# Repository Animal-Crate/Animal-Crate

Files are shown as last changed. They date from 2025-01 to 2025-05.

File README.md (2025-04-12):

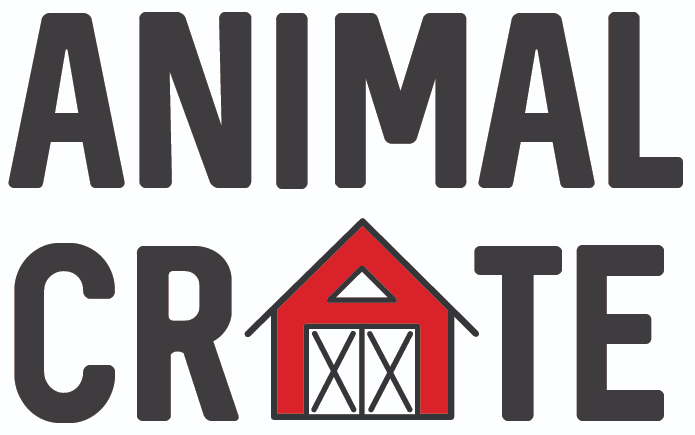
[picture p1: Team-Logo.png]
Animal Crate


This project is designed to create an animal noise toy that helps children to learn their animals and their sounds. It is specifically a toy that is meant to better cater to children and individuals with disabilities so that they can learn in a fun and constructive manner with a toy that is appealing and able to meet their needs.

This is a capstone project for the University of Kentucky ECE 490/491 that we are working on as a team. This is the public, open-source repository for this project and all code within this project falls under the provided license in this repository, AGPL-3.0 License. The provided schematics, CAD designs, and other resources are suggestions for recreating this project from home.

---

## Our Goal
The goal of this project is to design a child's toy that makes animal noises that is accessible to a wide-range of audiences, from children with disabilities or impairments to elderly with arthritis and compromised movement.

The provided code will be organized, commented, and user-friendly to allow for the ultimate configuration based on needs and systems. This is our goal as the members working on this project, to ensure that it is robust and well-rounded, allowing those without prior coding knowledge to make changes to suit their needs.

## Prerequisites
Before compiling the programming in this repository, some libraries are necessary for the Arduino IDE. These libraries are not all contained here due to licensing.

The following libraries are required for compiling and uploading to an ESP-32.
- The Animal Toy System utilizes the following libraries:
  - [Arduino LSM6DS3 Library](https://github.com/arduino-libraries/Arduino_LSM6DS3)
  - [DFPlayerMiniFast](https://github.com/PowerBroker2/DFPlayerMini_Fast)
- The Scanner System utilizes the following libraries:
  - [Adafruit ST7735 Library](https://github.com/adafruit/Adafruit-ST7735-Library) (For Testing)
  - [MFRC522](https://github.com/Animal-Crate/Animal-Crate/tree/master/MFRC522)
- The Sound System utilizes the following libraries:
  - [DFRobotDFPlayerMini](https://github.com/DFRobot/DFRobotDFPlayerMini)
  - [ESPSoftwareSerial](https://github.com/plerup/espsoftwareserial/)
- The Video/Algorithm System utilizes the following libraries:
  - [Adafruit GFX Library](https://github.com/adafruit/Adafruit-GFX-Library)
  - [Adafruit ILI9341 Library](https://github.com/adafruit/Adafruit_ILI9341)
  - [Adafruit ImageReader Library](https://github.com/adafruit/Adafruit_ImageReader)
  - [Adafruit SPIFlash](https://github.com/adafruit/Adafruit_SPIFlash)
  - [SdFat](https://github.com/greiman/SdFat)

## Acknowledgements
Please note that the files shown in [MFRC522](https://github.com/Animal-Crate/Animal-Crate/tree/master/_MFRC522) are taken from another repository. These are not licensed under this repository's license, and you can find more information in the README section in that directory.

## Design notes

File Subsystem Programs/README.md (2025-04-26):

The programs in this directory are intended for testing the individual systems within this project. This is a modular based project such that each subsystem can be tested individually to ensure they are working correctly and as intended. The programs are listed below for each part and how they work.

---
**NOTE**

These programs have **Prerequisites** for the libraries prior to compiling. It is suggested that you review these libraries on the front page to ensure that you have all of the necessary files for compiling in Arduino IDE. The links to the GitHub repositories for these are provided, but must be downloaded individually in the Arduino IDE if using it as the source for compilation to an ESP32 or other microcontroller.

---

### Algorithm-Feedback
The `Algorithm-Feedback.ino` file is used for testing the individual buttons (for the display), the display, and the learning/game modes within the program. This does not test the scanning and audio functions, but does test the display and buttons for manipulating the brightness, navigation, and functionality around the different modes in this project.

### Animal_Toy
The `Animal_Toy.ino` file is used for testing the individual toys and their functionalities, including the DFPlayer Minis that are used in each of the toys. This tests the gyro controls in the microcontrollers that were used in the toys, and is not necessary in the final project if ignoring the individual toys' functionality.

### Charge_Detection
The `Charge_Detection.ino` file is used for testing the functionality of the power LED in the system to display a color based on the charge of the system.

### Power-System_Debug
The `Power-System_Debug.ino` file is used for testing the functionality of a dedicated power system following the same design used in this project, which is 4 C-Type Batteries with components to step the voltage down for the required voltage for each of the parts used in this project in the other subsystems.

### Scanner_Debug & Scanner_Debug-Display
The `Scanner_Debug.ino` and `Scanner_Debug-Display.ino` files are used for testing the scanner functionality to serial connection and to display. These are intended to test the scanner and its primary functions within the project. The `Scanner_Debug.ino` tests the functionality of the Scanner itself without a display. The `Scanner_Debug-Display.ino` is intended to demonstrate the functionality of the Scanner in converting the UID of the NFC chip to a string value that can be used in the project.
- It is suggested to run both, if possible, to ensure that the NFC chips used have UIDs that can be properly displayed. The purpose of this is to ensure that the UID is within 32 characters, the maximum for the program, and that the display can show these appropriately so that it can be used within the program for comparing the animals later.

### Sound-System_Debug
The `Sound-System_Debug.ino`file is used for testing the audio subsystem by itself to ensure that the animals are played. This also tests the buttons associated with the sound system to ensure that they trigger the volume up/down and plays the audio. This is also used to ensure the correct wiring for the DFPlayer Mini. This is necessary for testing the functionality of the DFPlayer Mini due to the current draw.
- It is suggested to test the audio system by itself, since greater current draw, such as testing the scanner and display alongside the audio system, may cause issues with the DFPlayer Mini powering the speaker, depending on the speaker draw.

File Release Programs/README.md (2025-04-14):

This is the directory for releases. We will be posting updated programs for the releases here, and this will track the version history.

The `Control_Program-Serial_Debug.ino` file is a program for displaying to the Serial Window in the Arduino IDE.

The `Control_Program.ino` file is a program that does not display to Serial Window, but has the same functionality.

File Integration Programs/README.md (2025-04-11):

The provided files in this directory are for integration tests, and can be used to test multiple systems when recreating this project. Below are descriptions of the other files. Please refer to the [Prerequisites](https://github.com/Animal-Crate/Animal-Crate/blob/master/README.md) when downloading libraries for testing these integration programs.

### AV_ScannerIntegration
The `AV_ScannerIntegration.ino` file should be run in Arduino IDE for the appropriate setup. This may not perform correctly if executed in Platform IO due to the differences in the setup function for the display. This integration test is performed to ensure that the audio system, display/algorithm system, and scanner system work together.
- It is suggested to have the DFPlayer Mini running on a DC Power Supply at about 4.50 Volts and 0.021 A (21 mA) with a common ground for the ESP32 and DC Power Supply. The DFPlayer Mini, ILI9341 board, and scanner have a large combined amperage that the ESP32 may not be able to supply, causing the audio system to not work as intended.

### ScannerAudioIntegration
The `ScannerAudioIntegration.ino` file should be run in Arduino IDE, but may work in the Platform IO if necessary to test there. This integration test is performed to ensure the audio system works as intended alongside the scanner system, and is also a separate test for ensuring that the scanning system works as intended with NFC Chips that are written into the program. This does not contain the updated functions used in the `AV_ScannerIntegration.ino` file, but contains the same structure, so testing should work seamlessly across both systems when testing scanner and audio.

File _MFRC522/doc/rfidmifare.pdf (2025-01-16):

## Using a MFRC522 reader to read and write MIFARE RFID cards

on ARDUINO through the MFRC522 library BY COOQROBOT.
Mario Capurso (m.capurso@libero.it)

MIFARE is the NXP Semiconductors-owned trademark of a series of chips widely
used in contactless smart cards and proximity cards. According to the producers, billions of smart card chips and many millions of reader modules have been sold. [1]

The technology is owned by NXP Semiconductors (spin off from Philips Electronics in 2006) with headquarters in Eindhoven, Netherlands, and main business sites in Nijmegen, Netherlands, and Hamburg, Germany.

The MIFARE name covers proprietary technologies based upon various levels of the ISO/IEC 14443 Type A 13.56 MHz contactless smart card standard.
The MIFARE name (derived from the term MIkron FARE Collection System) covers
seven different kinds of contactless cards.

MIFARE Classic employs a proprietary protocol compliant to parts (but not all) of ISO/IEC 14443-3 Type A, with an NXP proprietary security protocol for authentication and ciphering.

The MIFARE Classic card is fundamentally just a memory storage device, where the memory is divided into segments and blocks with simple security mechanisms for access control. They are ASIC-based and have limited computational power. Thanks
to their reliability and low cost, those cards are widely used for electronic wallet, access control, corporate ID cards, transportation or stadium ticketing.

The MIFARE Classic 1K offers 1024 bytes of data storage, split into 16 sectors; each sector is protected by two different keys, called A and B. Each key can be programmed to allow operations such as reading, writing, increasing valueblocks, etc. MIFARE Classic 4K offers 4096 bytes split into forty sectors, of which 32 are same size as in the 1K with eight more that are quadruple size sectors. MIFARE Classic mini offers 320 bytes split into five sectors.

For each of these card types, 16 bytes per sector are reserved for the keys and access conditions and can not normally be used for user data. Also, the very first 16 bytes contain the serial number of the card and certain other manufacturer data and are read only. That brings the net storage capacity of these cards down to 752 bytes for MIFARE Classic 1k, 3440 bytes for MIFARE Classic 4k, and 224 bytes for Mini. It uses an NXP proprietary security protocol (Crypto-1) for authentication and ciphering.

The encryption used by the MIFARE Classic card uses a 48 bit key. [18]
A presentation by Henryk Plötz and Karsten Nohl[19] at the Chaos Communication Congress in December 2007 described a partial reverse-engineering of the algorithm used in the MIFARE Classic chip. Abstract and slides[20] are available online. A paper that describes the process of reverse engineering this chip was published at the August 2008 USENIX security conference.[21] (https://www.usenix.org/legacy/events/sec08/tech/full_papers/nohl/nohl.pdf)

In March 2008 the Digital Security[22] research group of the Radboud University Nijmegen made public that they performed a complete reverse-engineering and
were able to clone and manipulate the contents of an OV-Chipkaart which is a MIFARE Classic card.[23] (http://www.cs.ru.nl/~flaviog/publications/Talk.Mifare.pdf) For demonstration they used the Proxmark device, a 125 kHz / 13.56 MHz research instrument.[24] The schematics and software are released under the free GNU General Public License by Jonathan Westhues in 2007. They demonstrate it is even possible to perform card-only attacks using just an ordinary stock-commercial NFC reader in combination with the libnfc library.

In April 2009 new and better card-only attack on MIFARE Classic has been
found. It was first announced at the Rump session of Eurocrypt 2009.[35] This attack was presented at SECRYPT 2009.[36] The full description of this latest and fastest attack to date can also be found in the IACR preprint archive.[37] The new attack improves by a factor of more than 10 all previous card-only attacks on MIFARE Classic, has instant running time, and it does not require a costly precomputation.

The new attack allows to recover the secret key of any sector of MIFARE Classic card via wireless interaction, within about 300 queries to the card. It can then be combined with the nested authentication attack in the Nijmegen Oakland paper to recover subsequent keys almost instantly. Both attacks combined and with the right hardware equipment such as Proxmark3, one should be able to clone any MIFARE Classic card in not more than 10 seconds. This is much faster than previously thought.

The MFRC522 is a highly integrated reader/writer IC for contactless communication at 13.56 MHz. The MFRC522 reader supports ISO/IEC 14443 A/MIFARE mode.
The MFRC522’s internal transmitter is able to drive a reader/writer antenna designed to communicate with ISO/IEC 14443 A/MIFARE cards and transponders without additional active circuitry. The receiver module provides a robust and efficient implementation for demodulating and decoding signals from ISO/IEC 14443 A/MIFARE compatible cards and transponders. The digital module manages the complete ISO/IEC 14443 A framing and error detection (parity and CRC) functionality.

The MFRC522 supports all variants of the MIFARE Mini, MIFARE 1K, MIFARE 4K, MIFARE Ultralight, MIFARE DESFire EV1 and MIFARE Plus RF identification protocols. To aid readability throughout this data sheet, the MIFARE Mini,

MIFARE 1K, MIFARE 4K, MIFARE Ultralight, MIFARE DESFire EV1 and MIFARE Plus products and protocols have the generic name MIFARE.

The following host interfaces are provided:

- Serial Peripheral Interface (SPI)
- Serial UART (similar to RS232 with voltage levels dependant on pin voltage supply)
- I2C-bus interface


Answer to Request :

With the Answer to Request sequence the MIFARE® RWD (Read Write Device) requests all MIFARE® cards in the antenna field. When a card is in the operating range of a RWD, the RWD continues communication with the appropriate protocol.

Anticollision loop
In the Anticollision loop the serial number of the card is read. If there are several cards in the operating range of a RWD they can be distinguished by their different serial numbers and one can be selected (Select card) for further transactions. The unselected cards return to the standby mode and wait for a new Answer to Request and Anticollision loop.

Select Card
With the Select Card command the RWD selects one individual card for further authentication and memory related operations. The card returns the Answer to Select (ATS) code, which determines the individual type of the selected card.

Access Specification
After identification and selection of one card the RWD specifies the memory location of the following access.

Three Pass Authentication
The appropriate access key for the previously specified access is used for 3 Pass Authentication. Any communication after authentication is automatically encrypted at the sender and decrypted by the receiver.

Read/Write

After authentication any of the following operations may be performed:

READ | reads one block
WRITE | writes one block
DECREMENT | decrements the contents of one block and stores the result
| in the data-register
INCREMENT | increments the contents of one block and stores the result
| in the data-register
TRANSFER | writes the contents of the data-register to one block
RESTORE | stores the contents of one block in the data-register

The MF1ICS50 IC of a Mifare Classic has integrated a 8192 Bit EEPROM which is split into 16 sectors with 4 blocks. One block consists of 16 bytes (1 Byte = 8 Bit).


Manufacturer Code (Block 0 of Sector 0)

The first block of the memory is reserved for manufacturer data like 32 bit serial number. This is a read only block. In many documents it is named "Block 0".

Data Block (Block 0 to 3 except "Block 0")

Access conditions for the Data Blocks are defined in the Sector Trailers. According to these conditions data can be read, written, incremented, decremented, transferred or restored either with Key A, Key B or never.

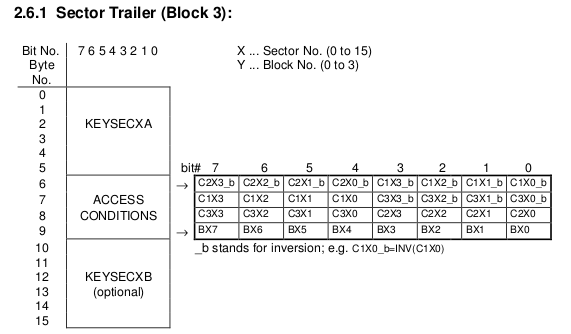
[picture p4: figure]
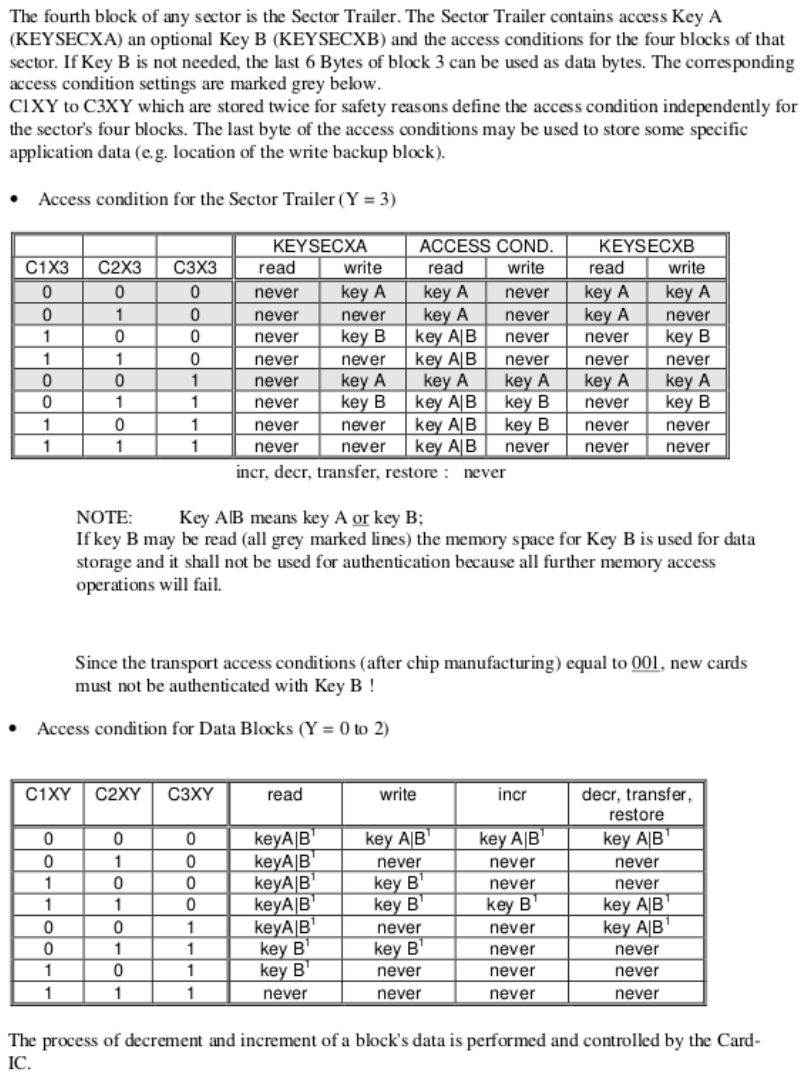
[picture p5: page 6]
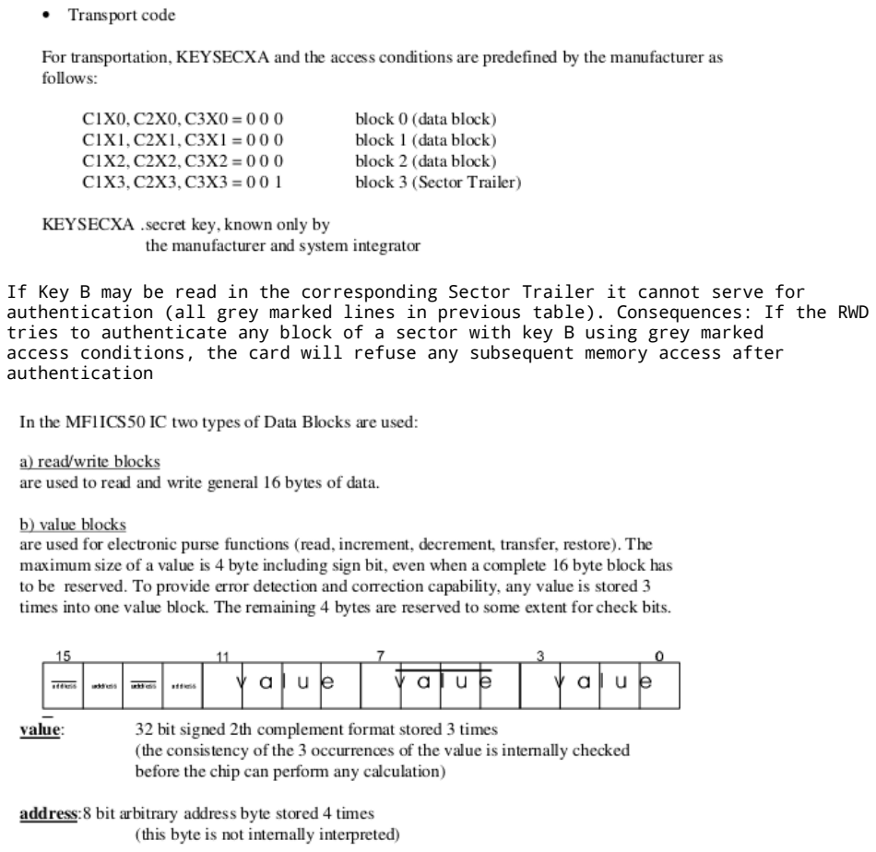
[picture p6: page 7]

If Key B may be read in the corresponding Sector Trailer it cannot serve for authentication (all grey marked lines in previous table). Consequences: If the RWD tries to authenticate any block of a sector with key B using grey marked
access conditions, the card will refuse any subsequent memory access after authentication

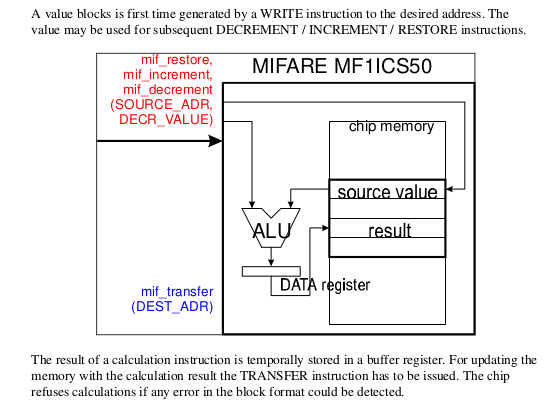
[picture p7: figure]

The described memory organization makes it possible to appoint different sectors to different applications and to prevent data corruption by using application specific secret keys. Keys can only be altered by a RWD which has stored the actual Key A or Key B if this is allowed according to access conditions. Otherwise the actual key cannot be changed anymore.

Before the execution of a command the correct format of the Access Conditions is checked by the Card-IC. Thus, when programming the Sector Trailer the card needs to be fixed within the operating range of a RWD's antenna to prevent interruption of the write operation because any unsuccessful write operation may lead to blocking the whole sector.

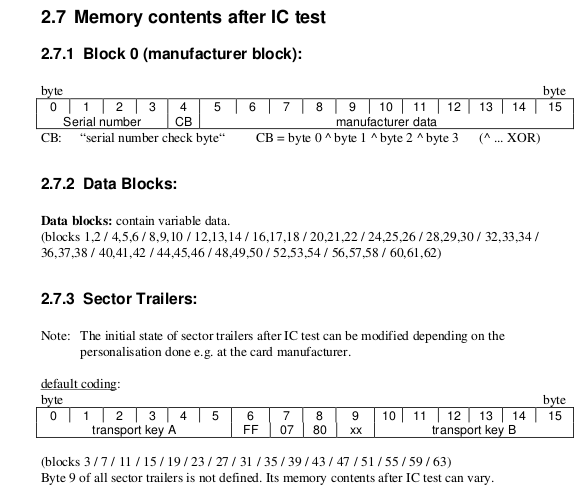
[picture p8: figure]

## MFRC522.h – A Library to use ARDUINO RFID MODULE KIT 13.56

MHZ BY COOQROBOT.

There are three hardware components involved:

1) The micro controller: An Arduino
2) The PCD (Proximity Coupling Device): NXP MFRC522 Contactless Reader IC
3) The PICC (short for Proximity Integrated Circuit Card): A card or tag using the ISO 14443A interface, eg Mifare or NTAG203.

MIFARE Classic 1K (MF1S503x):

Has 16 sectors * 4 blocks/sector * 16 bytes/block = 1024 bytes. The blocks are numbered 0-63.

Block 3 in each sector is the Sector Trailer.
* | Bytes 0-5: | Key A
* | Bytes 6-8: | Access Bits
* | Bytes 9: | User data
* | Bytes 10-15: Key B (or user data)

Block 0 is read only manufacturer data.

To access a block, an authentication using a key from the block's sector must be performed first.

Example: To read from block 10, first authenticate using a key from sector 3 (blocks 8-11).

All keys are set to FFFFFFFFFFFFh at chip delivery.

Warning: Please read section 8.7 "Memory Access". It includes this text: if the PICC detects a format violation the whole sector is irreversibly blocked.

To use a block in "value block" mode (for Increment/Decrement operations) you need to change the sector trailer. Use PICC_SetAccessBits() to calculate the bit patterns.

Commands sent to the PICC.

The commands used by the PCD to manage communication with several PICCs (ISO 14443-3, Type A, section 6.4)

PICC_CMD_REQA = 0x26,
REQuest command, Type A. Invites PICCs in state IDLE to go to READY and prepare for anticollision or selection. 7 bit frame.
PICC_CMD_WUPA = 0x52,
Wake-UP command, Type A. Invites PICCs in state IDLE and HALT to go to READY(*) and prepare for anticollision or selection. 7 bit frame.
PICC_CMD_CT = 0x88,
Cascade Tag. Not really a command, but used during anti collision. PICC_CMD_SEL_CL1 = 0x93,
Anti collision/Select, Cascade Level 1
PICC_CMD_SEL_CL2 = 0x95,
Anti collision/Select, Cascade Level 2 PICC_CMD_SEL_CL3 = 0x97,
Anti collision/Select, Cascade Level 3
PICC_CMD_HLTA = 0x50,
HaLT command, Type A. Instructs an ACTIVE PICC to go to state HALT.

The commands used for MIFARE Classic
Use PCD_MFAuthent to authenticate access to a sector, then use these commands to read/write/modify the blocks on the sector.
The read/write commands can also be used for MIFARE Ultralight.

PICC_CMD_MF_AUTH_KEY_A = 0x60,
Perform authentication with Key A
PICC_CMD_MF_AUTH_KEY_B = 0x61,
Perform authentication with Key B
PICC_CMD_MF_READ | = 0x30,
Reads one 16 byte block from the authenticated sector of the PICC. Also used for MIFARE Ultralight.
PICC_CMD_MF_WRITE | = 0xA0,
Writes one 16 byte block to the authenticated sector of the PICC. Called "COMPATIBILITY WRITE" for MIFARE Ultralight.
PICC_CMD_MF_DECREMENT = 0xC0,
Decrements the contents of a block and stores the result in the internal data register.
PICC_CMD_MF_INCREMENT = 0xC1,
Increments the contents of a block and stores the result in the internal data register.
PICC_CMD_MF_RESTORE | = 0xC2,
Reads the contents of a block into the internal data register. PICC_CMD_MF_TRANSFER = 0xB0,
Writes the contents of the internal data register to a block.

List of the functions in the library

Functions for setting up the Arduino

MFRC522(byte chipSelectPin, byte resetPowerDownPin);
void setSPIConfig();

Basic interface functions for communicating with the MFRC522

void PCD_WriteRegister(byte reg, byte value);
void PCD_WriteRegister(byte reg, byte count, byte *values);
byte PCD_ReadRegister(byte reg);
void PCD_ReadRegister(byte reg, byte count, byte *values, byte rxAlign = 0); void setBitMask(unsigned char reg, unsigned char mask);
void PCD_SetRegisterBitMask(byte reg, byte mask);
void PCD_ClearRegisterBitMask(byte reg, byte mask);
byte PCD_CalculateCRC(byte *data, byte length, byte *result);

Functions for manipulating the MFRC522

void PCD_Init();
void PCD_Reset();
void PCD_AntennaOn();

Functions for communicating with PICCs

byte PCD_TransceiveData(byte *sendData, byte sendLen, byte *backData, byte *backLen, byte *validBits = NULL, byte rxAlign = 0, bool checkCRC = false);

byte PCD_CommunicateWithPICC(byte command, byte waitIRq, byte *sendData, byte sendLen, byte *backData = NULL, byte *backLen = NULL, byte *validBits = NULL, byte rxAlign = 0, bool checkCRC = false);

byte PICC_RequestA(byte *bufferATQA, byte *bufferSize);
byte PICC_WakeupA(byte *bufferATQA, byte *bufferSize);
byte PICC_REQA_or_WUPA( byte command, byte *bufferATQA, byte *bufferSize); byte PICC_Select(Uid *uid, byte validBits = 0);
byte PICC_HaltA();

Functions for communicating with MIFARE PICCs

byte PCD_Authenticate(byte command, byte blockAddr, MIFARE_Key *key, Uid *uid); void PCD_StopCrypto1();
byte MIFARE_Read(byte blockAddr, byte *buffer, byte *bufferSize);
byte MIFARE_Write(byte blockAddr, byte *buffer, byte bufferSize);
byte MIFARE_Decrement(byte blockAddr, long delta);
byte MIFARE_Increment(byte blockAddr, long delta);
byte MIFARE_Restore(byte blockAddr);
byte MIFARE_Transfer(byte blockAddr);
byte MIFARE_Ultralight_Write(byte page, byte *buffer, byte bufferSize);

Support functions

byte PCD_MIFARE_Transceive( byte *sendData, byte sendLen, bool acceptTimeout = false);
const char *GetStatusCodeName(byte code);
byte PICC_GetType(byte sak);
const char *PICC_GetTypeName(byte type);
void PICC_DumpToSerial(Uid *uid);
void PICC_DumpMifareClassicToSerial(Uid *uid, byte piccType, MIFARE_Key *key);
void PICC_DumpMifareClassicSectorToSerial(Uid *uid, MIFARE_Key *key, byte sector); void PICC_DumpMifareUltralightToSerial();
void MIFARE_SetAccessBits(byte *accessBitBuffer, byte g0, byte g1, byte g2, byte g3);

Convenience functions - does not add extra functionality

bool PICC_IsNewCardPresent();
bool PICC_ReadCardSerial();

Detailed documentation – enum and structures

PICC types we can detect. Remember to update PICC_GetTypeName() if you add more.

enum PICC_Type

Return codes from the functions in this class. Remember to update GetStatusCodeName() if you add more.

enum StatusCode

A struct used for passing the UID of a PICC.

typedef struct {
byte | size; | Number of bytes in the UID. 4, 7 or 10.
byte | uidByte[10];
byte | sak; | The SAK (Select acknowledge) byte returned
| | from the PICC after successful selection.
} Uid

A struct used for passing a MIFARE Crypto1 key

typedef struct {
byte | keyByte[MF_KEY_SIZE];
} MIFARE_Key;

Example:
// Prepare key - all keys are set to FFFFFFFFFFFFh at chip delivery from the factory. MFRC522::MIFARE_Key key;
for (byte i = 0; i < 6; i++) key.keyByte[i] = 0xFF;

Member variables

Uid uid; | Used by PICC_ReadCardSerial().

Detailed documentation – functions

+Create object instance
MFRC522(
byte chipSelectPin, Arduino pin used for SPI chip select byte resetPowerDownPin Arduino pin used for SPI reset
);
Example:
#include <SPI.h>

#include <MFRC522.h>

#define SS_PIN 10 //Arduino Uno

#define RST_PIN 9

MFRC522 mfrc522(SS_PIN, RST_PIN); | // Create MFRC522 instance.

+Initializes the MFRC522 chip.
void MFRC522::PCD_Init()
Example:
void setup() {
Serial.begin(9600); | // Init serial communications with PC
SPI.begin(); | // Init SPI bus
mfrc522.PCD_Init(); | // Init MFRC522 card
}

+Set SPI bus to work with MFRC522 chip.

Please call this function if you have changed the SPI config since the MFRC522 constructor was run.

void MFRC522::setSPIConfig()

+Performs a soft reset on the MFRC522 chip and waits for it to be ready again. void MFRC522::PCD_Reset()

+Turns the antenna on by enabling pins TX1 and TX2.
After a reset these pins are disabled.
void MFRC522::PCD_AntennaOn()

+Transmits a REQuest command, Type A. Invites PICCs in state IDLE to go to READY and prepare for anticollision or selection. 7 bit frame.
Beware: When two PICCs are in the field at the same time I often get STATUS_TIMEOUT -probably due do bad antenna design.
return STATUS_OK on success, STATUS_??? otherwise.
byte MFRC522::PICC_RequestA(
byte *bufferATQA, The buffer to store the ATQA (Answer to request) in
byte *bufferSize Buffer size, at least two bytes. Also number of bytes returned if STATUS_OK.

+Transmits a Wake-UP command, Type A. Invites PICCs in state IDLE and HALT to go to READY(*) and prepare for anticollision or selection. 7 bit frame.
Beware: When two PICCs are in the field at the same time I often get STATUS_TIMEOUT -probably due do bad antenna design.
return STATUS_OK on success, STATUS_??? otherwise.
byte MFRC522::PICC_WakeupA(
byte *bufferATQA, The buffer to store the ATQA (Answer to request) in
byte *bufferSize Buffer size, at least two bytes. Also number of bytes returned if STATUS_OK.

+Transmits SELECT/ANTICOLLISION commands to select a single PICC.
Before calling this function the PICCs must be placed in the READY(*) state by calling PICC_RequestA() or PICC_WakeupA().
On success:

-The chosen PICC is in state ACTIVE(*) and all other PICCs have returned to state IDLE/HALT. (Figure 7 of the ISO/IEC 14443-3 draft.)
-The UID size and value of the chosen PICC is returned in *uid along with the SAK.

A PICC UID consists of 4, 7 or 10 bytes.
Only 4 bytes can be specified in a SELECT command, so for the longer UIDs two or three iterations are used:
UID size | Number of UID bytes | Cascade levels | Example of PICC
======== | =================== | ============== | ===============
single | 4 | 1 | MIFARE Classic
double | 7 | 2 | MIFARE Ultralight
triple | 10 | 3 | Not currently in use?

return STATUS_OK on success, STATUS_??? otherwise.
byte MFRC522::PICC_Select(
Uid *uid, | Pointer to Uid struct. Normally output, but can also
be used to supply a known UID.
byte validBits | The number of known UID bits supplied in *uid.

Normally 0. If set you must also supply uid->size.

Description of buffer structure:

Byte 0: SEL | Indicates the Cascade Level: PICC_CMD_SEL_CL1,
PICC_CMD_SEL_CL2 or PICC_CMD_SEL_CL3
Byte 1: NVB | Number of Valid Bits (in complete command, not just the UID):
High nibble: complete bytes, Low nibble: Extra bits.
Byte 2: UID-data or CT See explanation below. CT means Cascade Tag.
Byte 3: UID-data
Byte 4: UID-data
Byte 5: UID-data
Byte 6: BCC | Block Check Character - XOR of bytes 2-5
Byte 7: CRC_A
Byte 8: CRC_A

The BCC and CRC_A is only transmitted if we know all the UID bits of the current Cascade Level.
Description of bytes 2-5: (Section 6.5.4 of the ISO/IEC 14443-3 draft: UID contents and cascade levels)
UID size | Cascade level | Byte2 Byte3 Byte4 Byte5
======== | ============= | ===== ===== ===== =====
4 bytes | 1 | uid0 uid1 uid2 uid3

7 bytes | 1 | CT | uid0 uid1 uid2
2 | uid3 uid4 uid5 uid6
10 bytes | 1 | CT | uid0 uid1 uid2
| 2 | CT | uid3 uid4 uid5

+Instructs a PICC in state ACTIVE(*) to go to state HALT. return STATUS_OK on success, STATUS_??? otherwise.
byte PICC_HaltA();
Example:
// Halt PICC
mfrc522.PICC_HaltA();

+Executes the MFRC522 MFAuthent command.
This command manages MIFARE authentication to enable a secure communication to any MIFARE Mini, MIFARE 1K and MIFARE 4K card.
The authentication is described in the MFRC522 datasheet section 10.3.1.9 and http://www.nxp.com/documents/data_sheet/MF1S503x.pdf section 10.1. for use with MIFARE Classic PICCs.
The PICC must be selected - ie in state ACTIVE(*) - before calling this function. Remember to call PCD_StopCrypto1() at the end of communication with the authenticated PICC - otherwise no new communications can start.
All keys are set to FFFFFFFFFFFFh at chip delivery.
return STATUS_OK on success, STATUS_??? otherwise. Probably STATUS_TIMEOUT if you supply the wrong key.
byte MFRC522::PCD_AuthenticateI(
byte command, | PICC_CMD_MF_AUTH_KEY_A or PICC_CMD_MF_AUTH_KEY_B
byte blockAddr, | The block number. See numbering in the comments in
| the .h file.
MIFARE_Key *key, | Pointer to the Crypto1 key to use (6 bytes)
Uid *uid | Pointer to Uid struct. The first 4 bytes of the UID
| is used.
)
Example:
MFRC522::MIFARE_Key key;
for (byte i = 0; i < 6; i++) key.keyByte[i] = 0xFF; byte trailerBlock = 7;
byte status;
if ( ! mfrc522.PICC_ReadCardSerial()) return;
status = mfrc522.PCD_Authenticate(MFRC522::PICC_CMD_MF_AUTH_KEY_A, trailerBlock, &key, &(mfrc522.uid));
if (status != MFRC522::STATUS_OK) {
Serial.print("PCD_Authenticate() failed: "); Serial.println(mfrc522.GetStatusCodeName(status)); return;
}

+Used to exit the PCD from its authenticated state.
Remember to call PCD_StopCrypto1() at the end of communication with the authenticated PICC - otherwise no new communications can start.
void MFRC522::PCD_StopCrypto1()
Example:
// Stop encryption on PCD
mfrc522.PCD_StopCrypto1();

+Reads 16 bytes (+ 2 bytes CRC_A) from the active PICC.
For MIFARE Classic the sector containing the block must be authenticated before calling this function.
For MIFARE Ultralight only addresses 00h to 0Fh are decoded.
* The MF0ICU1 returns a NAK for higher addresses.

* The MF0ICU1 responds to the READ command by sending 16 bytes starting from
the page address defined by the command argument.
* For example; if blockAddr is 03h then pages 03h, 04h, 05h, 06h are returned.
* A roll-back is implemented: If blockAddr is 0Eh, then the contents of pages 0Eh, 0Fh, 00h and 01h are returned.
The buffer must be at least 18 bytes because a CRC_A is also returned.
Checks the CRC_A before returning STATUS_OK.
return STATUS_OK on success, STATUS_??? otherwise.
byte MFRC522::MIFARE_Read(
byte blockAddr, | MIFARE Classic: The block (0-0xff) number.
| MIFARE Ultralight: The first page to return data from.
byte *buffer, | The buffer to store the data in

byte *bufferSize Buffer size, at least 18 bytes. Also number of bytes returned
| if STATUS_OK.
Example:
byte valueBlockA = 4; byte buffer[18]; byte size = sizeof(buffer);
byte status = mfrc522.MIFARE_Read(valueBlockA, buffer, &size);

+Writes 16 bytes to the active PICC.
For MIFARE Classic the sector containing the block must be authenticated before calling this function.
For MIFARE Ultralight the operation is called "COMPATIBILITY WRITE".
Even though 16 bytes are transferred to the Ultralight PICC, only the least significant 4 bytes (bytes 0 to 3) are written to the specified address. It is recommended to set the remaining bytes 04h to 0Fh to all logic 0.
return STATUS_OK on success, STATUS_??? otherwise.
byte MFRC522::MIFARE_Write(
byte blockAddr,
| MIFARE Classic: The block (0-0xff) number.
| MIFARE Ultralight: The page (2-15) to write to.
byte *buffer, | The 16 bytes to write to the PICC
byte bufferSize | Buffer size, must be at least 16 bytes. Exactly 16 bytes are
| written.
Example:
byte valueBlockA = 4;
byte value1Block[] = { 1,2,3,4, 5,6,7,8, 9,10,255,12, 13,14,15,16}; status = mfrc522.MIFARE_Write(valueBlockA, value1Block, 16);
if (status != MFRC522::STATUS_OK) {
Serial.print("MIFARE_Write() failed: "); Serial.println(mfrc522.GetStatusCodeName(status));
}

+MIFARE Decrement subtracts the delta from the value of the addressed block, and stores the result in a volatile memory.
For MIFARE Classic only. The sector containing the block must be authenticated before calling this function.
Only for blocks in "value block" mode, ie with access bits [C1 C2 C3] = [110] or [001].
Use MIFARE_Transfer() to store the result in a block.
return STATUS_OK on success, STATUS_??? otherwise.
byte MFRC522::MIFARE_Decrement(
byte blockAddr, | The block (0-0xff) number.
long delta | This number is subtracted from the value of block blockAddr.

+MIFARE Increment adds the delta to the value of the addressed block, and stores the result in a volatile memory.
For MIFARE Classic only. The sector containing the block must be authenticated before calling this function.
Only for blocks in "value block" mode, ie with access bits [C1 C2 C3] = [110] or

[001].
Use MIFARE_Transfer() to store the result in a block. return STATUS_OK on success, STATUS_??? otherwise.
byte MFRC522::MIFARE_Increment(
byte blockAddr, | The block (0-0xff) number.
long delta | This number is added to the value of block blockAddr.
Example:
// Add 1 to the value of valueBlockA and store the result in valueBlockA. byte valueBlockA = 5;
Serial.print("Adding 1 to value of block "); Serial.println(valueBlockA); byte status = mfrc522.MIFARE_Increment(valueBlockA, 1);
if (status != MFRC522::STATUS_OK) {
Serial.print("MIFARE_Increment() failed: "); Serial.println(mfrc522.GetStatusCodeName(status)); return;
}
status = mfrc522.MIFARE_Transfer(valueBlockA);
if (status != MFRC522::STATUS_OK) { Serial.print("MIFARE_Transfer() failed: "); Serial.println(mfrc522.GetStatusCodeName(status)); return;
}

+MIFARE Restore copies the value of the addressed block into a volatile memory.
For MIFARE Classic only. The sector containing the block must be authenticated before calling this function.
Only for blocks in "value block" mode, ie with access bits [C1 C2 C3] = [110] or [001].
Use MIFARE_Transfer() to store the result in a block.
return STATUS_OK on success, STATUS_??? otherwise.
byte MFRC522::MIFARE_Restore(
byte blockAddr The block (0-0xff) number.
The datasheet describes Restore as a two step operation, but does not explain what data to transfer in step 2.Doing only a single step does not work, so I chose to transfer 0L in step two.

+Helper function for the two-step MIFARE Classic protocol operations Decrement, Increment and Restore.
return STATUS_OK on success, STATUS_??? otherwise.
byte MFRC522::MIFARE_TwoStepHelper(
byte command, | The command to use
byte blockAddr, | The block (0-0xff) number.
long data | The data to transfer in step 2
)

+MIFARE Transfer writes the value stored in the volatile memory into one MIFARE Classic block.
For MIFARE Classic only. The sector containing the block must be authenticated before calling this function.
Only for blocks in "value block" mode, ie with access bits [C1 C2 C3] = [110] or [001].
return STATUS_OK on success, STATUS_??? otherwise.
byte MFRC522::MIFARE_Transfer(
byte blockAddr The block (0-0xff) number.

+Returns a string pointer to a status code name. const char *MFRC522::GetStatusCodeName(
byte code | One of the StatusCode enums.
code values | return values

STATUS_OK: | "Success."
STATUS_ERROR: | "Error in communication."
STATUS_COLLISION: | "Collision detected."
STATUS_TIMEOUT: | "Timeout in communication."
STATUS_NO_ROOM: | "A buffer is not big enough."
STATUS_INTERNAL_ERROR: "Internal error in the code. Should not happen."
STATUS_INVALID: | "Invalid argument."
STATUS_CRC_WRONG: | "The CRC_A does not match."
STATUS_MIFARE_NACK: | "A MIFARE PICC responded with NAK."
default: | "Unknown error"

Example:
Serial.println(mfrc522.GetStatusCodeName(status));

+Translates the SAK (Select Acknowledge) to a PICC type. return PICC_Type
byte MFRC522::PICC_GetType(
byte sak | The SAK byte returned from PICC_Select().
sak | return value
sak & 0x04 | PICC_TYPE_NOT_COMPLETE
0x09 | PICC_TYPE_MIFARE_MINI
0x08 | PICC_TYPE_MIFARE_1K
0x18 | PICC_TYPE_MIFARE_4K
0x00 | PICC_TYPE_MIFARE_UL
0x10 or 0x11 | PICC_TYPE_MIFARE_PLUS
0x01 | PICC_TYPE_TNP3XXX
sak & 0x20 | PICC_TYPE_ISO_14443_4
sak & 0x40 | PICC_TYPE_ISO_18092
else | PICC_TYPE_UNKNOWN

+Returns a string pointer to the PICC type name. const char *MFRC522::PICC_GetTypeName(
byte piccType | One of the PICC_Type enums.
piccType | return value
PICC_TYPE_ISO_14443_4 | "PICC compliant with ISO/IEC 14443-4"
PICC_TYPE_ISO_18092: | "PICC compliant with ISO/IEC 18092 (NFC)"
PICC_TYPE_MIFARE_MINI | "MIFARE Mini, 320 bytes"
PICC_TYPE_MIFARE_1K | "MIFARE 1KB"
PICC_TYPE_MIFARE_4K | "MIFARE 4KB"
PICC_TYPE_MIFARE_UL | "MIFARE Ultralight or Ultralight C"
PICC_TYPE_MIFARE_PLUS | "MIFARE Plus"
PICC_TYPE_TNP3XXX | "MIFARE TNP3XXX"
PICC_TYPE_NOT_COMPLETE "SAK indicates UID is not complete."
PICC_TYPE_UNKNOWN | "Unknown type”
Example:
Serial.println(mfrc522.PICC_GetTypeName(piccType));

+Dumps debug info about the selected PICC to Serial.
On success the PICC is halted after dumping the data.
For MIFARE Classic the factory default key of 0xFFFFFFFFFFFF is tried. void MFRC522::PICC_DumpToSerial(
Uid *uid Pointer to Uid struct returned from a successful PICC_Select(). Example:
mfrc522.PICC_DumpToSerial(&(mfrc522.uid));

+Dumps memory contents of a sector of a MIFARE Classic PICC.
Uses PCD_Authenticate(), MIFARE_Read() and PCD_StopCrypto1.

Always uses PICC_CMD_MF_AUTH_KEY_A because only Key A can always read the sector trailer access bits.
void MFRC522::PICC_DumpMifareClassicSectorToSerial(
Uid *uid, | Pointer to Uid struct returned from a successful PICC_Select()
MIFARE_Key *key, Key A for the sector.
byte sector | The sector to dump, 0..39.

+Calculates the bit pattern needed for the specified access bits. In the [C1 C2 C3] tuples C1 is MSB (=4) and C3 is LSB (=1).
void MFRC522::MIFARE_SetAccessBits(
byte *accessBitBuffer, Pointer to byte 6, 7 and 8 in the sector trailer.
| Bytes [0..2] will be set.
byte g0, | Access bits [C1 C2 C3] for block 0 (for sectors 0-31) or blocks 0-4 (for sectors 32-39)
byte g1, | Access bits C1 C2 C3] for block 1 (for sectors 0-31) or blocks 5-9 (for sectors 32-39)
byte g2, | Access bits C1 C2 C3] for block 2 (for sectors 0-31) or blocks 10-14 (for sectors 32-39)
byte g3 | Access bits C1 C2 C3] for the sector trailer, block 3 (for sectors 0-31) or block 15 (for sectors 32-39)

The access bits are stored in a peculiar fashion.
There are four groups:

g[3] Access bits for the sector trailer, block 3 (for sectors 0-31) or block 15 (for sectors 32-39)

g[2] Access bits for block 2 (for sectors 0-31) or blocks 10-14 (for sectors 32-39) g[1] Access bits for block 1 (for sectors 0-31) or blocks 5-9 (for sectors 32-39) g[0] Access bits for block 0 (for sectors 0-31) or blocks 0-4 (for sectors 32-39)

Each group has access bits [C1 C2 C3]. In this code C1 is MSB and C3 is LSB.
The four CX bits are stored together in a nibble cx and an inverted nibble cx_. Example:
// Sector trailer that defines blocks 5 and 6 as Value Blocks and enables key B. byte trailerBuffer[] = {255,255,255,255,255,255,0,0,0,0, 255,255,255,255,255,255}; // Keep default keys.
// g1=6(i.e.110) => block 5 value block. Key B write&increment, A or B decrement. // g2=6 => Same thing for block 6.
// g3=3 => Key B must be used to modify the Sector Trailer. Key B becomes valid. mfrc522.MIFARE_SetAccessBits(&trailerBuffer[6], 0, 6, 6, 3);

+Check if a card is present
bool MFRC522::PICC_IsNewCardPresent()
Returns true if a PICC responds to PICC_CMD_REQA.
Only "new" cards in state IDLE are invited. Sleeping cards in state HALT are ignored. Example:
// Look for new cards
if ( ! mfrc522.PICC_IsNewCardPresent()) return;

+Read Card Serial
bool MFRC522::PICC_ReadCardSerial()
Simple wrapper around PICC_Select.
Returns true if a UID could be read.The read UID is available in the class variable uid.
Remember to call PICC_IsNewCardPresent(), PICC_RequestA() or PICC_WakeupA() first. return true if one selected

Now a card is selected. The UID and SAK is in mfrc522.uid. Example:
Serial.print("Card UID:");
for (byte i = 0; i < mfrc522.uid.size; i++) { Serial.print(mfrc522.uid.uidByte[i] < 0x10 ? " 0" : " "); Serial.print(mfrc522.uid.uidByte[i], HEX);
}
// Dump PICC type
byte piccType = mfrc522.PICC_GetType(mfrc522.uid.sak); Serial.print("PICC type: "); Serial.println(mfrc522.PICC_GetTypeName(piccType));
if ( piccType != MFRC522::PICC_TYPE_MIFARE_MINI
&& piccType != MFRC522::PICC_TYPE_MIFARE_1K
&& | piccType != MFRC522::PICC_TYPE_MIFARE_4K) {
Serial.println("This sample only works with MIFARE Classic cards."); return;
}

How to convert a normal block into a value block
Usually a normal block has 000 access bits, while a value block has 110 access bits Example:
byte valueBlockA = 5;
byte valueBlockB = 6;
byte trailerBlock = 7;
// We need a sector trailer with blocks 5 and 6 as Value Blocks and enables key B. byte trailerBuffer[] = { 255,255,255,255,255,255,
| 0,0,0,0,255,255,255,255,255,255}; // Keep default keys.
// g1=6 => block 5 as value block. Key B to write&increment, A or B for decrement. // g2=6 => Same thing for block 6.
// g3=3 => Key B must be used to modify the Sector Trailer. Key B becomes valid. mfrc522.MIFARE_SetAccessBits(&trailerBuffer[6], 0, 6, 6, 3);
byte status = mfrc522.MIFARE_Write(trailerBlock, trailerBuffer, 16);
if (status != MFRC522::STATUS_OK) {
Serial.print("MIFARE_Write() failed: "); Serial.println(mfrc522.GetStatusCodeName(status));
return;
}

How to setup a Value Block with a value set to zero Example:
byte blockAddr=5;
byte valueBlock[] = {0,0,0,0, 255,255,255,255, 0,0,0,0,
| blockAddr,~blockAddr,blockAddr,~blockAddr };
byte status = mfrc522.MIFARE_Write(blockAddr, valueBlock, 16); if (status != MFRC522::STATUS_OK) { Serial.print("MIFARE_Write() failed: "); Serial.println(mfrc522.GetStatusCodeName(status));
}

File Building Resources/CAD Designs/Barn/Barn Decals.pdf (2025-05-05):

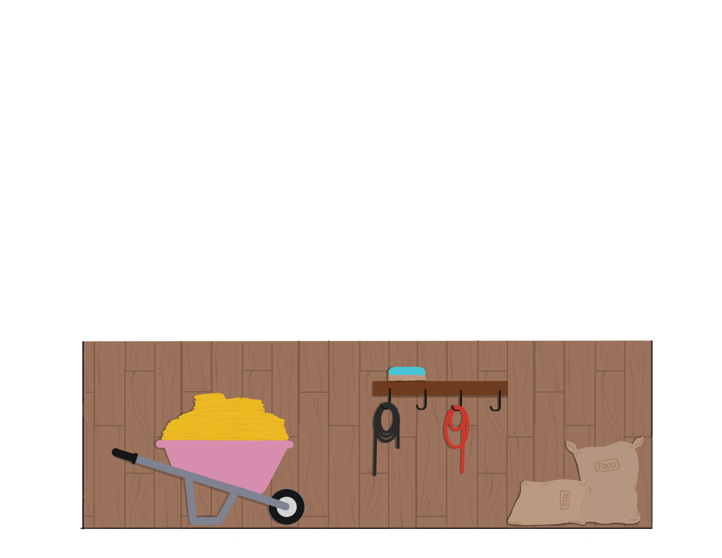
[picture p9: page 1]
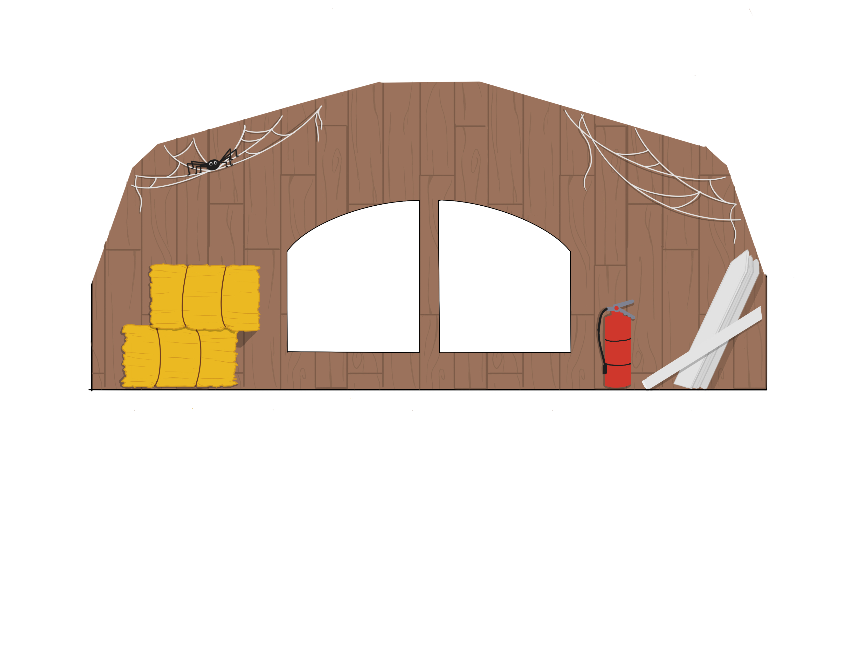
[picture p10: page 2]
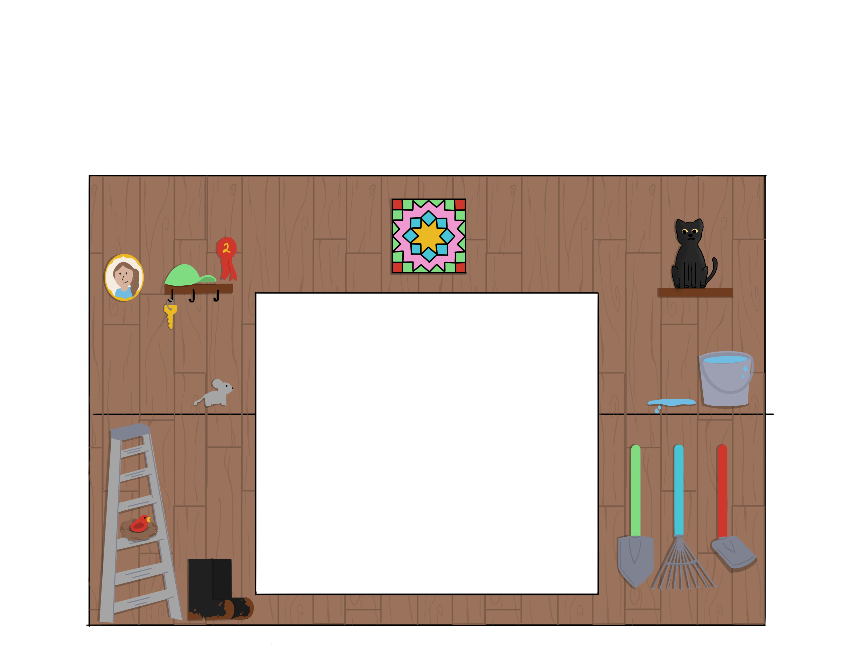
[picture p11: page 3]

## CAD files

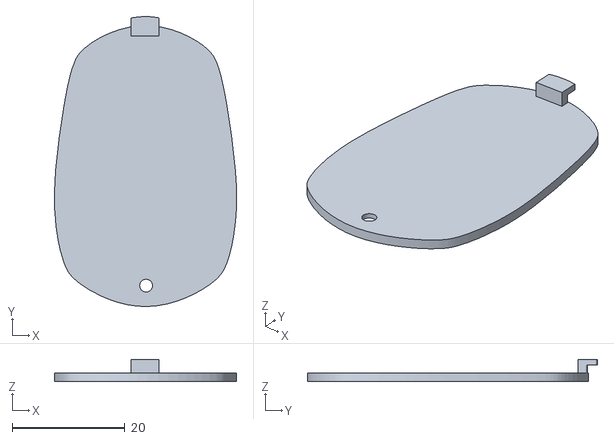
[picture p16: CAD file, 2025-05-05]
Building Resources/CAD Designs/Animals/bottom panel.stl
32.4 x 51.5 x 3.94

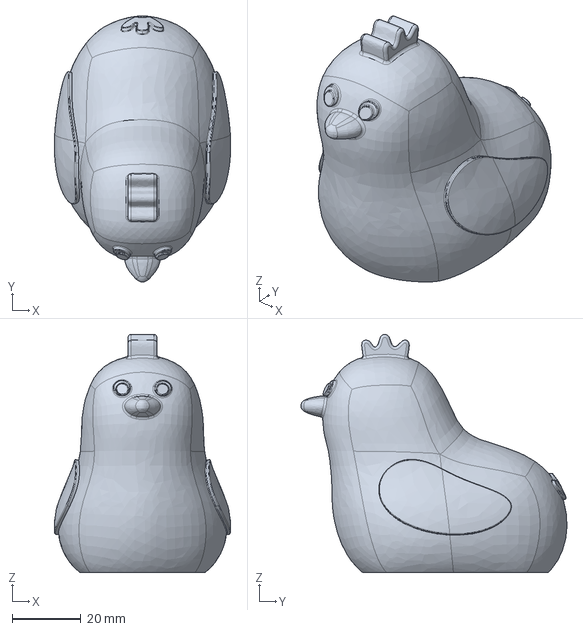
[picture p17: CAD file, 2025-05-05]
Building Resources/CAD Designs/Animals/Chicken/chicken model.step
51.3 x 77.5 x 69.4 mm

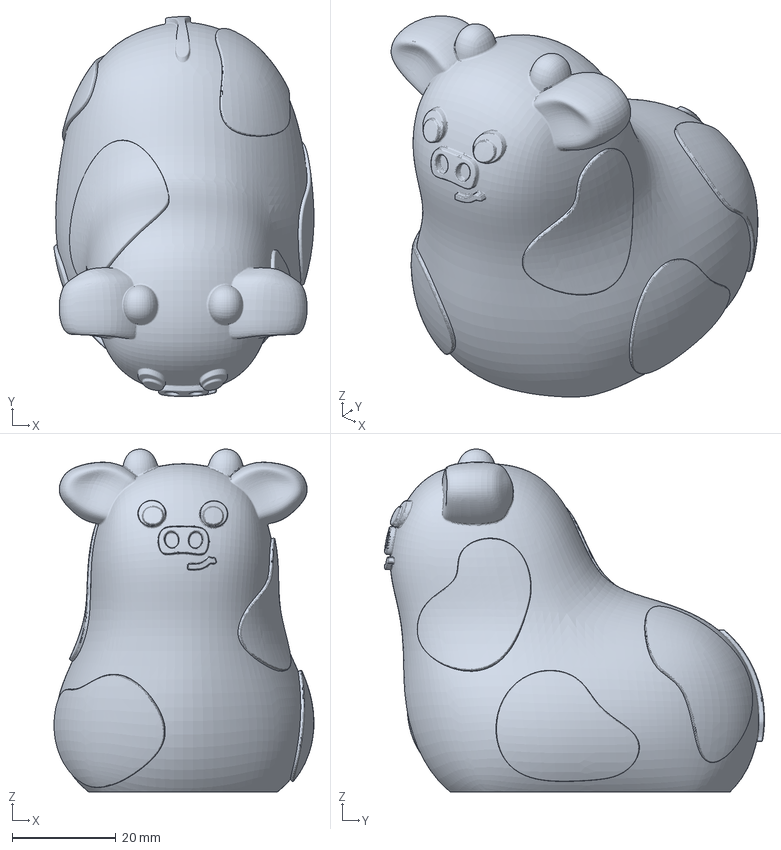
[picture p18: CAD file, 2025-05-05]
Building Resources/CAD Designs/Animals/Cow/cow color.3mf
50.2 x 73.3 x 66.2 mm

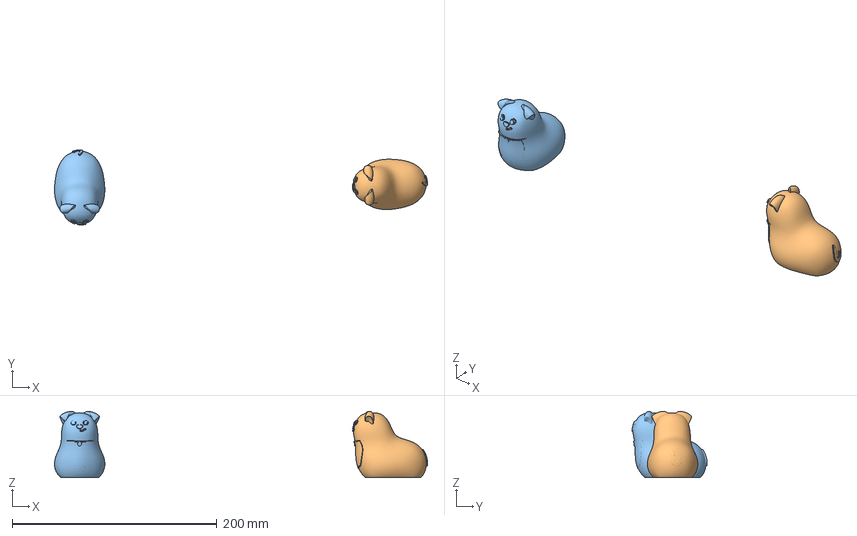
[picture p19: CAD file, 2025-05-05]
Building Resources/CAD Designs/Animals/Dog/dog color.3mf
364.1 x 73.4 x 64.7 mm
dog v23.stl x 3

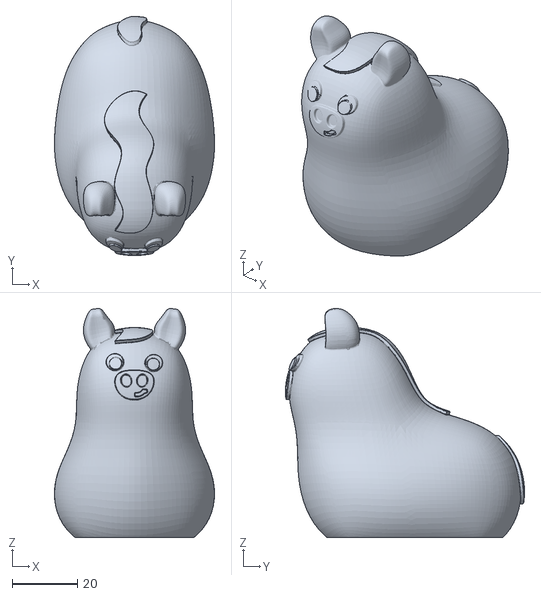
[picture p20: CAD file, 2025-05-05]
Building Resources/CAD Designs/Animals/Horse/horse.stl
49.1 x 73.4 x 70.3

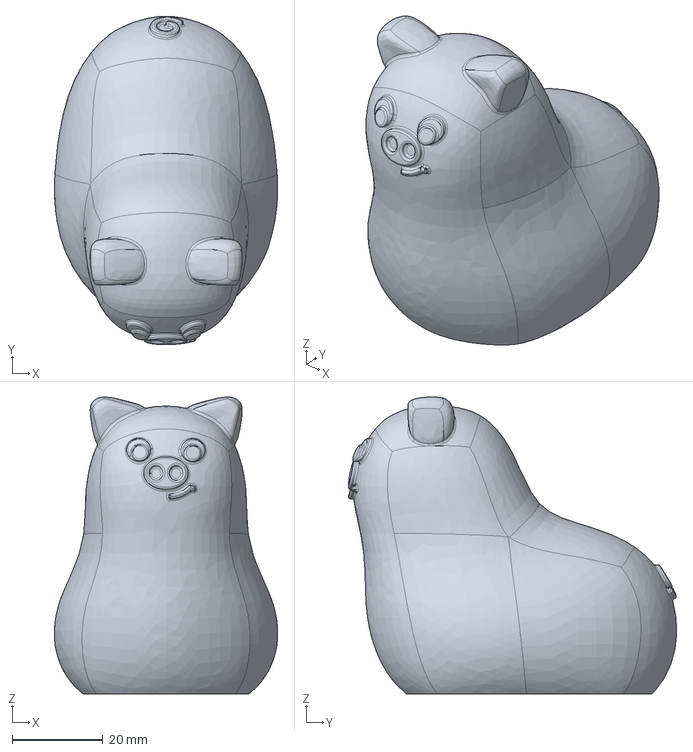
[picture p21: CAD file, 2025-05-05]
Building Resources/CAD Designs/Animals/Pig/pig model.step
49.2 x 72.3 x 65.4 mm

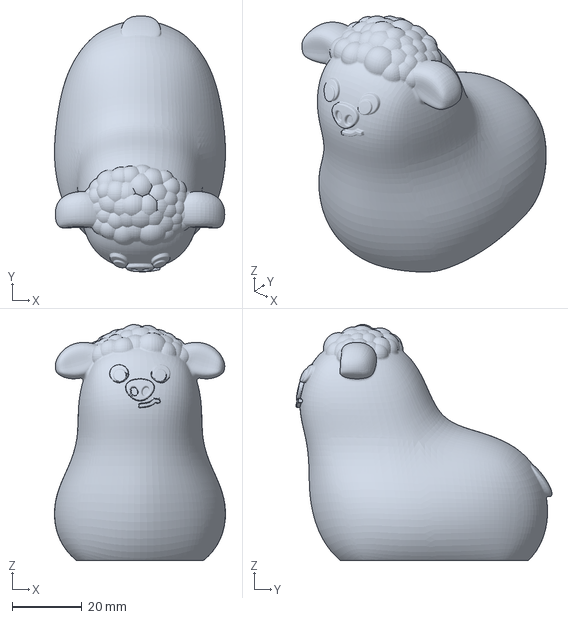
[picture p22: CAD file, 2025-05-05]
Building Resources/CAD Designs/Animals/Sheep/sheep color.3mf
49.1 x 73.5 x 67.8 mm

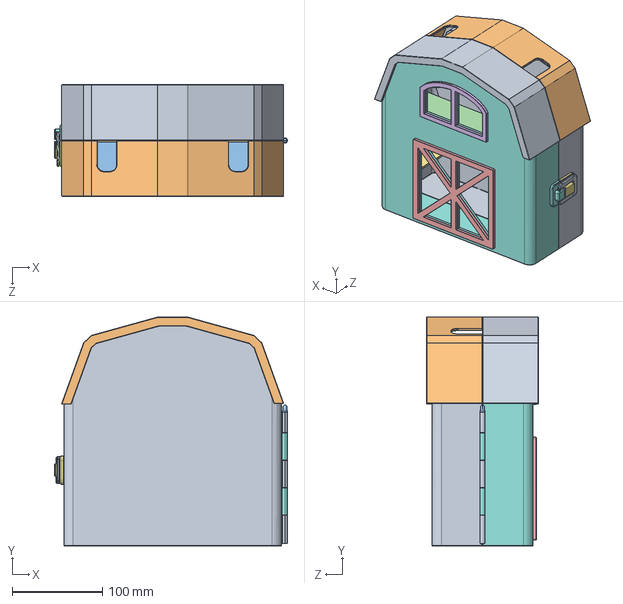
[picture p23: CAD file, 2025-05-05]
Building Resources/CAD Designs/Barn/barn model.STEP
258.5 x 254.0 x 124.0 mm

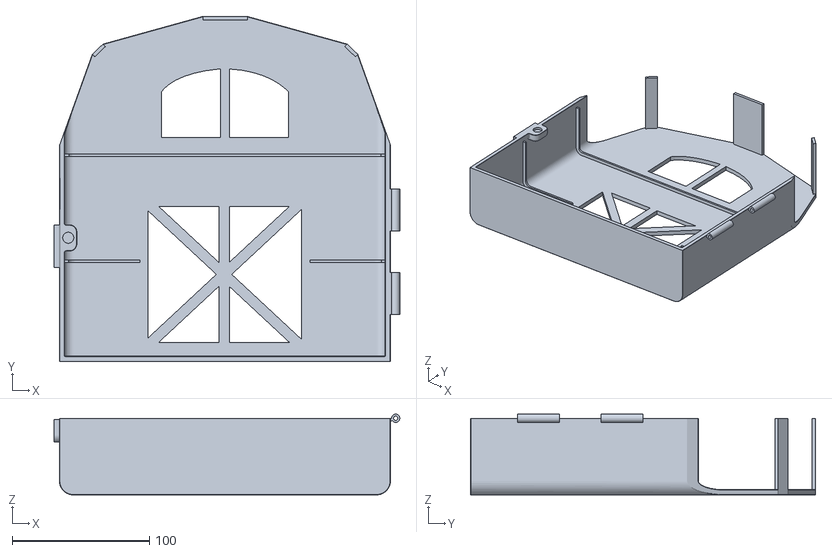
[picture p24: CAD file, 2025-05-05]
Building Resources/CAD Designs/Barn/Body/Barn Body Front.STL
252.0 x 251.5 x 58.9

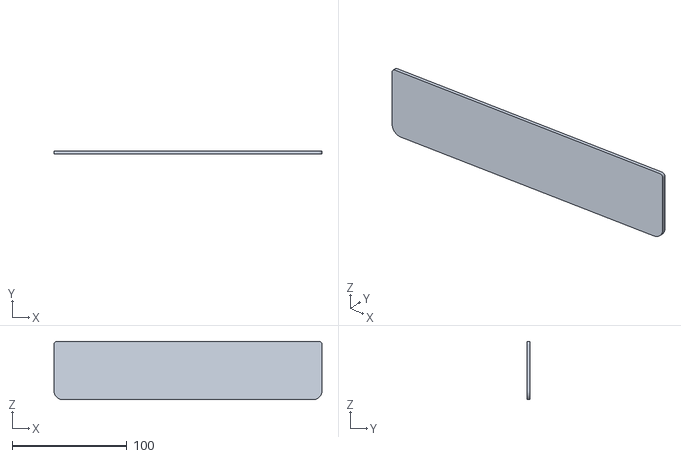
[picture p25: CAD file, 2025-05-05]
Building Resources/CAD Designs/Barn/Shelves/EEBarn5shelf4.STL
233.2 x 2.54 x 50.7

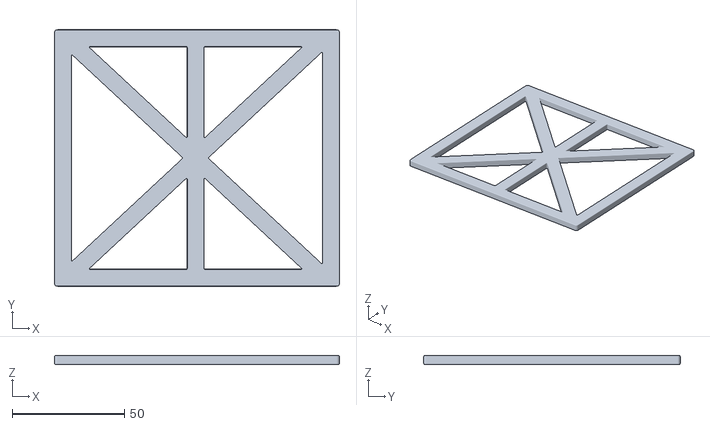
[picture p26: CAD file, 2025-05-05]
Building Resources/CAD Designs/Barn/Small Parts/door frame.STL
127.0 x 114.3 x 3.81

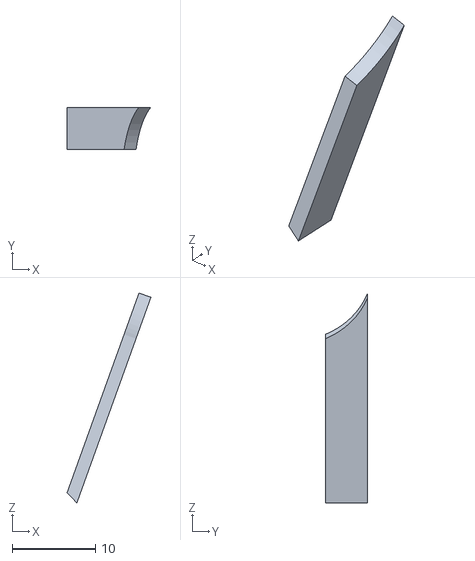
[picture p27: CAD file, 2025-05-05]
Building Resources/CAD Designs/Tablet/Fence Pieces/fence 2 hole 2.STL
10.0 x 5.08 x 25.2

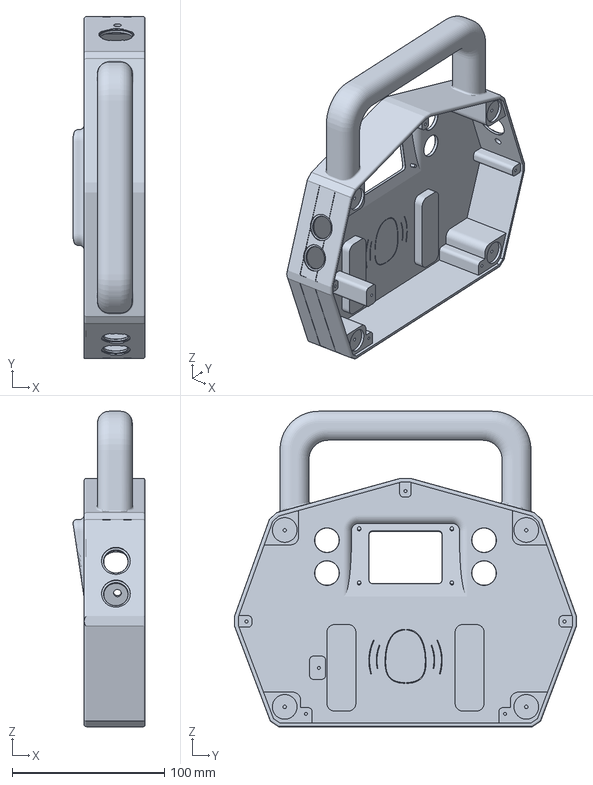
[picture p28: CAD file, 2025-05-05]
Building Resources/CAD Designs/Tablet/tablet color.3mf
47.3 x 224.8 x 207.4 mm

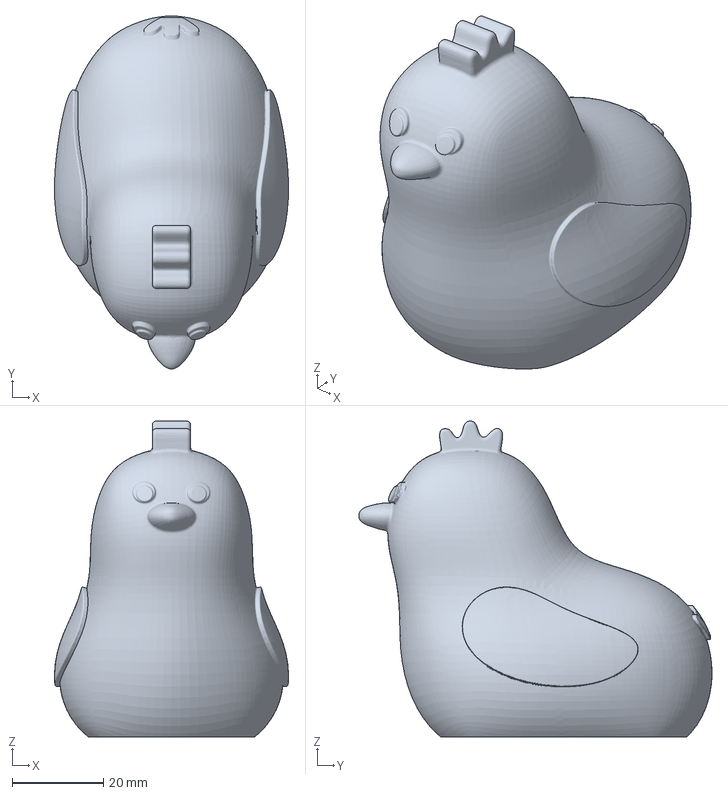
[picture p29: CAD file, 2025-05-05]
Building Resources/CAD Designs/Animals/Chicken/chicken color.3mf
51.4 x 77.5 x 69.4 mm

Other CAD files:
Building Resources/CAD Designs/Animals/Cow/cow.stl
Building Resources/CAD Designs/Animals/Dog/dog.stl
Building Resources/CAD Designs/Animals/Horse/horse color.3mf
Building Resources/CAD Designs/Animals/inside panel.stl
Building Resources/CAD Designs/Animals/Chicken/chicken.stl
Building Resources/CAD Designs/Animals/Dog/dog model.step
Building Resources/CAD Designs/Animals/Horse/horse model.step
Building Resources/CAD Designs/Animals/Pig/pig color.3mf
Building Resources/CAD Designs/Animals/Pig/pig.stl
Building Resources/CAD Designs/Animals/Sheep/sheep.stl
Building Resources/CAD Designs/Barn/Body/Barn Body Back.STL
Building Resources/CAD Designs/Barn/Shelves/EEBarn5shelf1.STL
Building Resources/CAD Designs/Barn/Shelves/EEBarn5shelf2.STL
Building Resources/CAD Designs/Barn/Shelves/EEBarn5shelf3.STL
Building Resources/CAD Designs/Barn/Small Parts/hinge cap.STL
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

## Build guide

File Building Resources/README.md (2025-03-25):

The following directory has resources that were used for building or piecing together modules for the project. These correspond to different parts of the main project.

The can include, but are not limited to:
- Pinouts
- CAD Files
- Organization of Parts
- and more.

### Correspondence
Some files here are documentation of the building portion of this project. Some files correspond to testing parts and have remained despite removal of outdated material.
- FP - Pinout.txt: Pinout for testing the display and using it with debugging for the NFC chips.

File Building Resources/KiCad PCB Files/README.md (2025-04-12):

The files in this directory are component files for the PCB boards used in this project, created in the [KiCad](https://www.kicad.org/) Software.

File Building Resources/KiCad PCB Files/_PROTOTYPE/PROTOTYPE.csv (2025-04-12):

Net Code | Net Name | Pad Count | Via Count | Via Length (mm) | Track Length (mm) | Die Length (mm) | Net Length (mm) | F.Cu (mm) | B.Cu (mm)
001 | GNDREF | 15 | 2 | 3.2000 | 309.6872 | 0.0000 | 312.8872 | 8.0000 | 301.6872
002 | +6V | 6 | 0 | 0.0000 | 123.7516 | 0.0000 | 123.7516 | 0.0000 | 123.7516
003 | Net-(J12-Pin_1) | 6 | 0 | 0.0000 | 42.0074 | 0.0000 | 42.0074 | 0.0000 | 42.0074
004 | Net-(D1-K) | 3 | 0 | 0.0000 | 56.6025 | 0.0000 | 56.6025 | 0.0000 | 56.6025
006 | Net-(D2-A) | 3 | 0 | 0.0000 | 12.9400 | 0.0000 | 12.9400 | 0.0000 | 12.9400
009 | Net-(J1-Pin_1) | 2 | 0 | 0.0000 | 29.5095 | 0.0000 | 29.5095 | 0.0000 | 29.5095
010 | Net-(J1-Pin_2) | 2 | 0 | 0.0000 | 31.1016 | 0.0000 | 31.1016 | 0.0000 | 31.1016
011 | Net-(J2-Pin_2) | 2 | 0 | 0.0000 | 26.5520 | 0.0000 | 26.5520 | 0.0000 | 26.5520
012 | Net-(J2-Pin_1) | 2 | 0 | 0.0000 | 23.7502 | 0.0000 | 23.7502 | 0.0000 | 23.7502
013 | Net-(J3-Pin_2) | 2 | 0 | 0.0000 | 20.6682 | 0.0000 | 20.6682 | 0.0000 | 20.6682
014 | Net-(J3-Pin_1) | 2 | 0 | 0.0000 | 22.8139 | 0.0000 | 22.8139 | 0.0000 | 22.8139
015 | Net-(J4-Pin_1) | 2 | 0 | 0.0000 | 17.5359 | 0.0000 | 17.5359 | 0.0000 | 17.5359
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

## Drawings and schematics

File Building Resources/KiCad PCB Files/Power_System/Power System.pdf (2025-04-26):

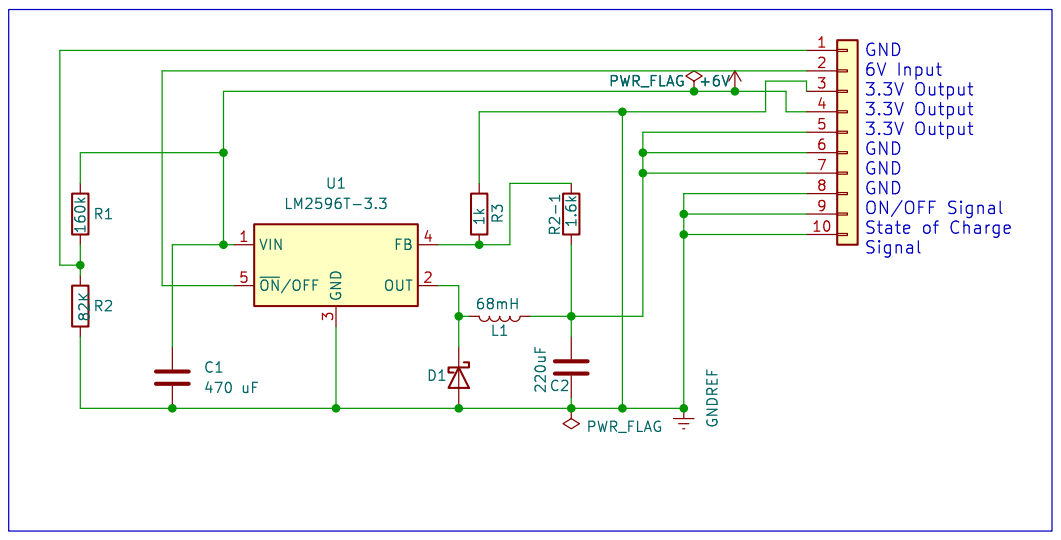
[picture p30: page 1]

Id: 1/1 Title: File: Power System.kicad_sch Sheet: /

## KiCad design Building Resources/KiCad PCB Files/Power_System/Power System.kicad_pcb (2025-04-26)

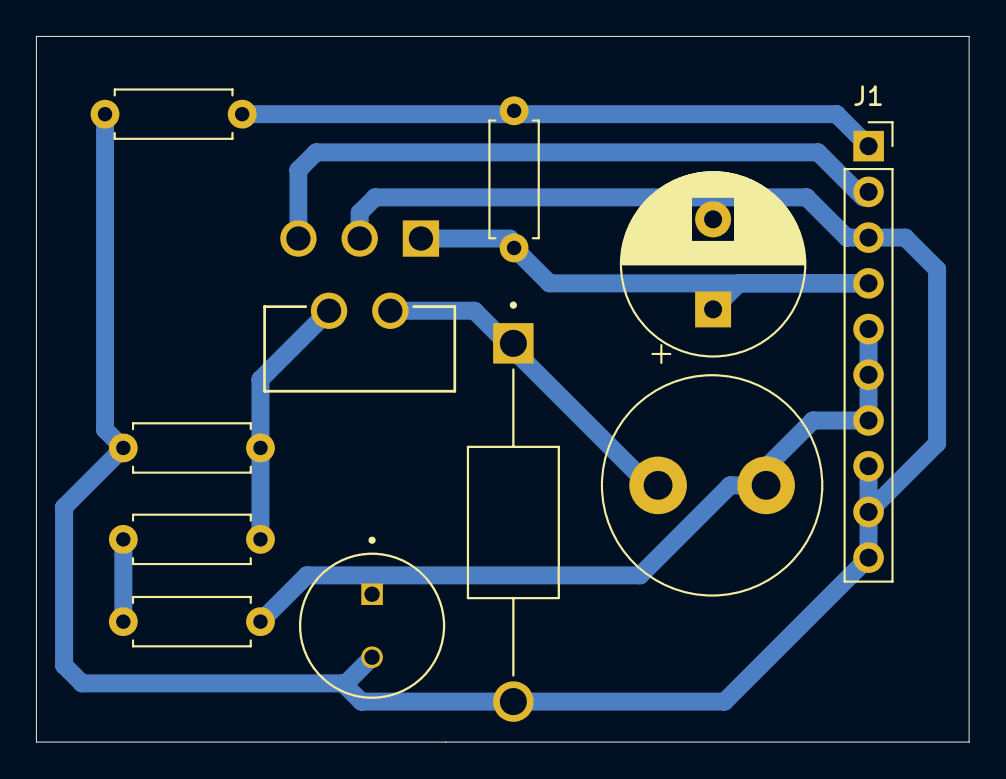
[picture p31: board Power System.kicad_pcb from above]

Board: 2 copper layers, 51.8 x 39.2 mm, 11 parts (0 on the bottom side), 8 nets.

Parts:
C1: 470 uF; CP_Radial_D10.0mm_P5.00mm
C2: 220uF; 220uFRadialTHCAP
D1: D_Schottky; DIOAD1990W125L840D530
J1: Conn_01x10; PinSocket_1x10_P2.54mm_Vertical
L1: 68mH; L_Radial_D12.0mm_P6.00mm_Murata_1900R
R1: 160k; R_Axial_DIN0207_L6.3mm_D2.5mm_P7.62mm_Horizontal
R2: 82K; R_Axial_DIN0207_L6.3mm_D2.5mm_P7.62mm_Horizontal
R2-1, R2-2: 1.6k; R_Axial_DIN0207_L6.3mm_D2.5mm_P7.62mm_Horizontal
R3: 1k; R_Axial_DIN0207_L6.3mm_D2.5mm_P7.62mm_Horizontal
U1: LM2596T-3.3; TO170P470X1016X2092-5P

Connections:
+6V: C1.1, J1.4, R1.1, U1.1 (VIN)
GNDREF: C1.2, C2.2, D1.2 (A), J1.3, J1.8, J1.9, J1.10, R2.2, R3.1, U1.3 (GND)
unnamed: D1.1 (K), L1.2, U1.2 (OUT)
unnamed: J1.1, R1.2, R2.1
unnamed: J1.2, U1.5 (~ON/OFF)
unnamed: C2.1, J1.5, J1.6, J1.7, L1.1, R2-2.2
unnamed: R2-1.2, R2-2.1
unnamed: R2-1.1, R3.2, U1.4 (FB)

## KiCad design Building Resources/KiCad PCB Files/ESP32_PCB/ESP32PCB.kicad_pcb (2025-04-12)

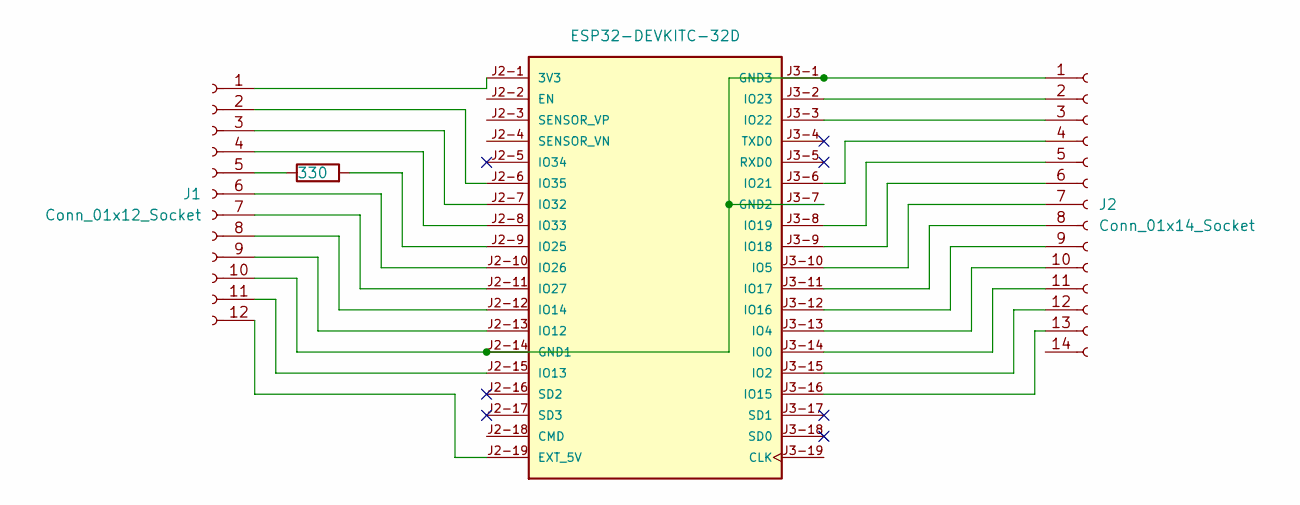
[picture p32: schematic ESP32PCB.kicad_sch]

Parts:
J1: Conn_01x12_Socket; PinSocket_1x12_P2.54mm_Vertical
J2: Conn_01x14_Socket; PinSocket_1x14_P2.54mm_Vertical
R1: 330; R_Axial_DIN0207_L6.3mm_D2.5mm_P7.62mm_Horizontal
U1: ESP32-DEVKITC-32D; MODULE_ESP32-DEVKITC-32D; PARTREV V4

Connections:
unnamed: J1.1, U1.J2-1 (3V3)
unnamed: J1.2, U1.J2-6 (IO35)
unnamed: J1.3, U1.J2-7 (IO32)
unnamed: J1.4, U1.J2-8 (IO33)
unnamed: J1.5, R1.1
unnamed: J1.6, U1.J2-10 (IO26)
unnamed: J1.7, U1.J2-11 (IO27)
unnamed: J1.8, U1.J2-12 (IO14)
unnamed: J1.9, U1.J2-13 (IO12)
unnamed: J1.10, J2.1, U1.J2-14 (GND1), U1.J3-1 (GND3), U1.J3-7 (GND2)
unnamed: J1.11, U1.J2-15 (IO13)
unnamed: J1.12, U1.J2-19 (EXT_5V)
unnamed: J2.2, U1.J3-2 (IO23)
unnamed: J2.3, U1.J3-3 (IO22)
unnamed: J2.4, U1.J3-6 (IO21)
unnamed: J2.5, U1.J3-8 (IO19)
unnamed: J2.6, U1.J3-9 (IO18)
unnamed: J2.7, U1.J3-10 (IO5)
unnamed: J2.8, U1.J3-11 (IO17)
unnamed: J2.9, U1.J3-12 (IO16)
unnamed: J2.10, U1.J3-13 (IO4)
unnamed: J2.11, U1.J3-14 (IO0)
unnamed: J2.12, U1.J3-15 (IO2)
unnamed: J2.13, U1.J3-16 (IO15)
unnamed: R1.2, U1.J2-9 (IO25)

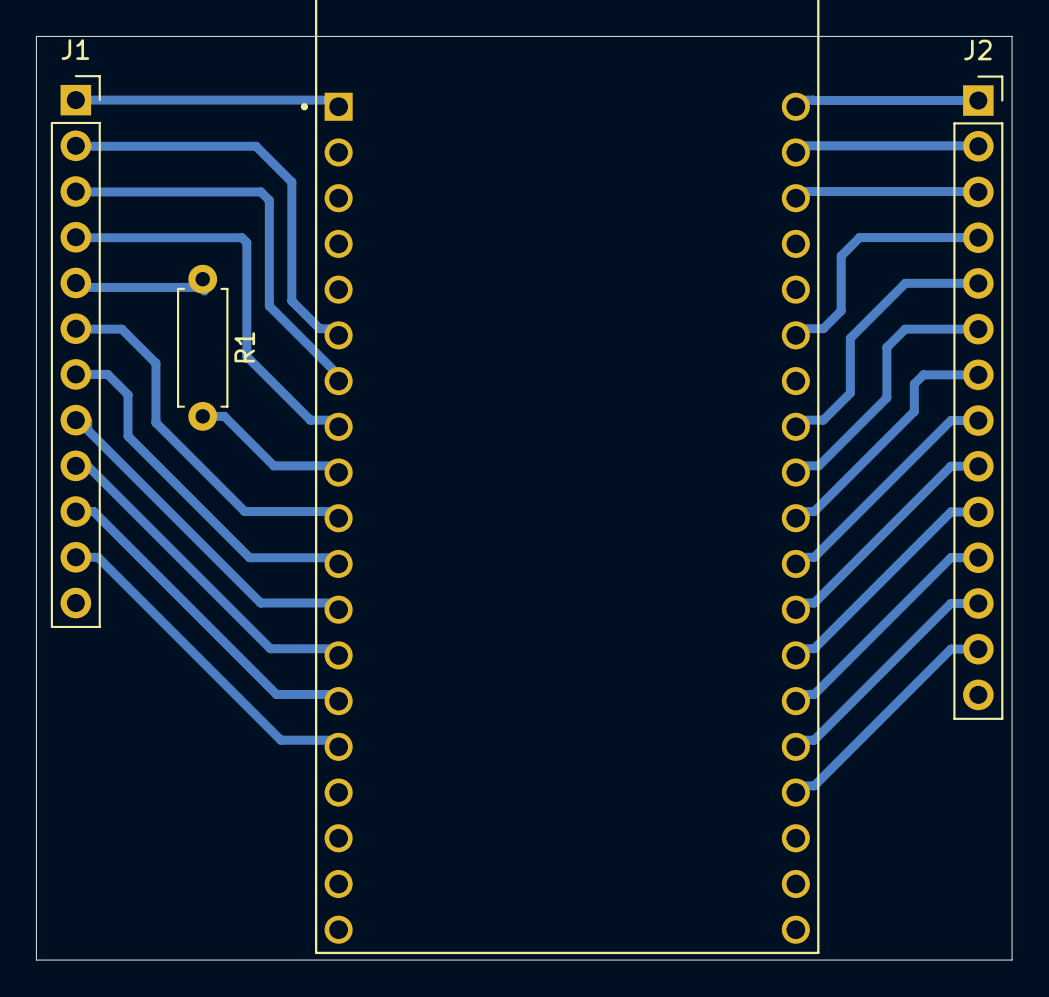
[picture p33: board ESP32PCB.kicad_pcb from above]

Board: 2 copper layers, 54.2 x 51.3 mm, 4 parts (0 on the bottom side), 25 nets.

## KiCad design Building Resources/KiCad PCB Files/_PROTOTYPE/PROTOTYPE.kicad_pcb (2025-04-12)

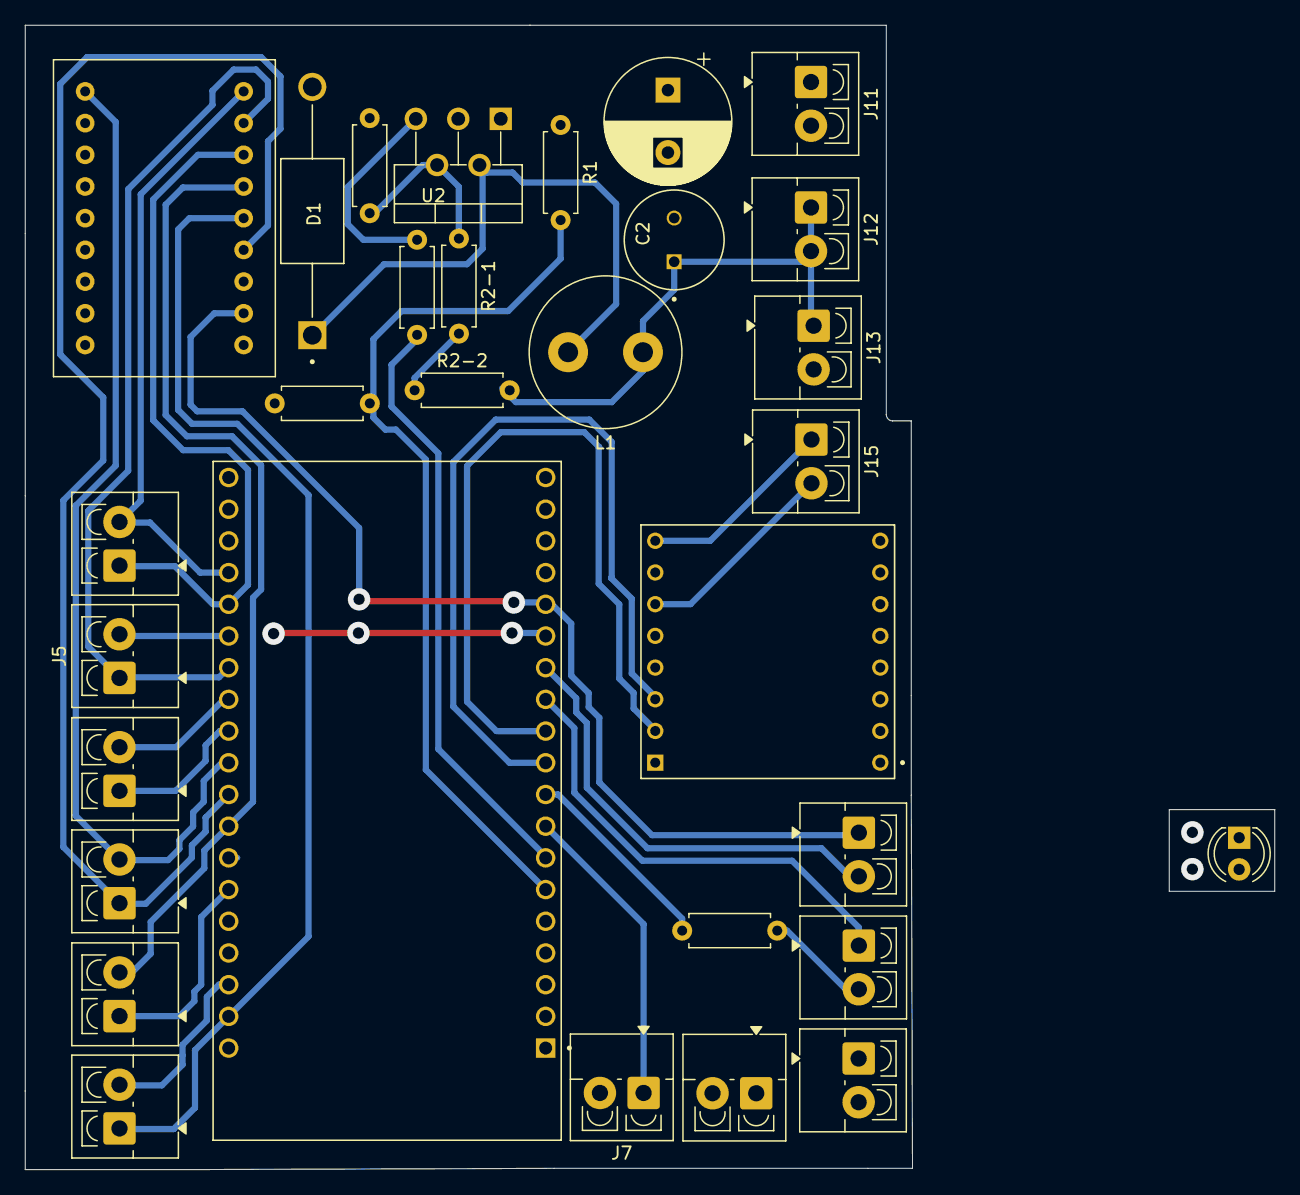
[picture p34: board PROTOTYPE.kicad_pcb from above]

Board: 2 copper layers, 71.1 x 91.7 mm, 31 parts (0 on the bottom side), 32 nets.

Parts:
C1: 470 uF; CP_Radial_D10.0mm_P5.00mm
C2: 220u; 220uFRadialTHCAP
D1: D_Schottky; DIOAD1990W125L840D530
D2: RED; LED_D4.0mm
EYESPI_18IN_BREAKOUT_BOARD1: DIP-18_500
J1: 2322; TerminalBlock_4Ucon_1x02_P3.50mm_Vertical
J2: 2129; TerminalBlock_4Ucon_1x02_P3.50mm_Vertical
J3: 1805; TerminalBlock_4Ucon_1x02_P3.50mm_Vertical
J4: 1716; TerminalBlock_4Ucon_1x02_P3.50mm_Vertical
J5: 0400; TerminalBlock_4Ucon_1x02_P3.50mm_Vertical
J6: 0215; TerminalBlock_4Ucon_1x02_P3.50mm_Vertical
J7: 33; TerminalBlock_4Ucon_1x02_P3.50mm_Vertical
J8: 2514; TerminalBlock_4Ucon_1x02_P3.50mm_Vertical
J10: 1213; TerminalBlock_4Ucon_1x02_P3.50mm_Vertical
J11: BATTERY TERMS; TerminalBlock_4Ucon_1x02_P3.50mm_Vertical
J12: 3.3V; TerminalBlock_4Ucon_1x02_P3.50mm_Vertical
J13: 3.3V AND GND; TerminalBlock_4Ucon_1x02_P3.50mm_Vertical
J14: GND; TerminalBlock_4Ucon_1x02_P3.50mm_Vertical
J15: SPKR; TerminalBlock_4Ucon_1x02_P3.50mm_Vertical
J16: LED'S AND GND; TerminalBlock_4Ucon_1x02_P3.50mm_Vertical
L1: 68m; L_Radial_D12.0mm_P6.00mm_Murata_1900R
R1: 160k; R_Axial_DIN0207_L6.3mm_D2.5mm_P7.62mm_Horizontal
R2: 82K; R_Axial_DIN0207_L6.3mm_D2.5mm_P7.62mm_Horizontal
R2-1: 18k; R_Axial_DIN0207_L6.3mm_D2.5mm_P7.62mm_Horizontal
R2-2: 120k; R_Axial_DIN0207_L6.3mm_D2.5mm_P7.62mm_Horizontal
R3, R6: 330; R_Axial_DIN0207_L6.3mm_D2.5mm_P7.62mm_Horizontal
R7: 82k; R_Axial_DIN0207_L6.3mm_D2.5mm_P7.62mm_Horizontal
U1: DFR0299
U2: LM2596T-3.3; TO-220-5_P3.4x3.7mm_StaggerOdd_Lead3.8mm_Vertical
U3: ESP32-DEVKITC-32D; MODULE_ESP32-DEVKITC-32D

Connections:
+3.3V: J16.1, U3.J2-1 (3V3)
+6V: C1.1, J11.1, R1.1, U1.1 (VCC), U2.1 (VIN), U3.J2-19 (EXT_5V)
GNDREF: C1.2, C2.2, D1.2 (A), EYESPI_18IN_BREAKOUT_BOARD1.3 (Gnd), J11.2, J13.2, J14.1, J14.2, J16.2, R2.2, R7.1, U1.7 (GND), U2.3 (GND), U3.J2-14 (GND1), U3.J3-1 (GND3), U3.J3-7 (GND2)
unnamed: D1.1 (K), L1.2, U2.2 (OUT)
unnamed: EYESPI_18IN_BREAKOUT_BOARD1.7 (DC), J6.1, U3.J3-15 (IO2)
unnamed: EYESPI_18IN_BREAKOUT_BOARD1.2 (Lite), J10.1, U3.J2-15 (IO13)
unnamed: EYESPI_18IN_BREAKOUT_BOARD1.6 (MISO), J2.2, U3.J3-8 (IO19)
unnamed: EYESPI_18IN_BREAKOUT_BOARD1.5 (MOSI), J1.1, U3.J3-2 (IO23)
unnamed: EYESPI_18IN_BREAKOUT_BOARD1.8 (RST), J5.1, U3.J3-13 (IO4)
unnamed: EYESPI_18IN_BREAKOUT_BOARD1.4 (SCK), J3.1, U3.J3-9 (IO18)
unnamed: EYESPI_18IN_BREAKOUT_BOARD1.10 (SDCS), J3.2, U3.J3-10 (IO5)
unnamed: EYESPI_18IN_BREAKOUT_BOARD1.9 (TCS), J6.2, U3.J3-16 (IO15)
unnamed: C2.1, EYESPI_18IN_BREAKOUT_BOARD1.1 (Vin), J12.1, J12.2, J13.1, L1.1, R2-2.2
unnamed: J1.2, U3.J3-3 (IO22)
unnamed: J2.1, U3.J3-6 (IO21)
unnamed: J4.1, U3.J3-11 (IO17)
unnamed: J4.2, U3.J3-12 (IO16)
unnamed: J5.2, U3.J3-14 (IO0)
unnamed: J7.1, U3.J2-8 (IO33)
unnamed: J8.1, U3.J2-12 (IO14)
unnamed: J8.2, R6.1
unnamed: J10.2, U3.J2-13 (IO12)
unnamed: J15.1, U1.8 (SPK2)
unnamed: J15.2, U1.6 (SPK1)
unnamed: R2-1.2, R2-2.1
unnamed: U1.2 (RX), U3.J2-11 (IO27)
unnamed: U1.3 (TX), U3.J2-10 (IO26)
unnamed: R2-1.1, R7.2, U2.4 (FB)
unnamed: R3.1, U2.5 (~ON/OFF)
unnamed: R6.2, U3.J2-9 (IO25)
unnamed: R3.2, U3.J2-7 (IO32)
unnamed: R1.2, R2.1, U3.J2-6 (IO35)

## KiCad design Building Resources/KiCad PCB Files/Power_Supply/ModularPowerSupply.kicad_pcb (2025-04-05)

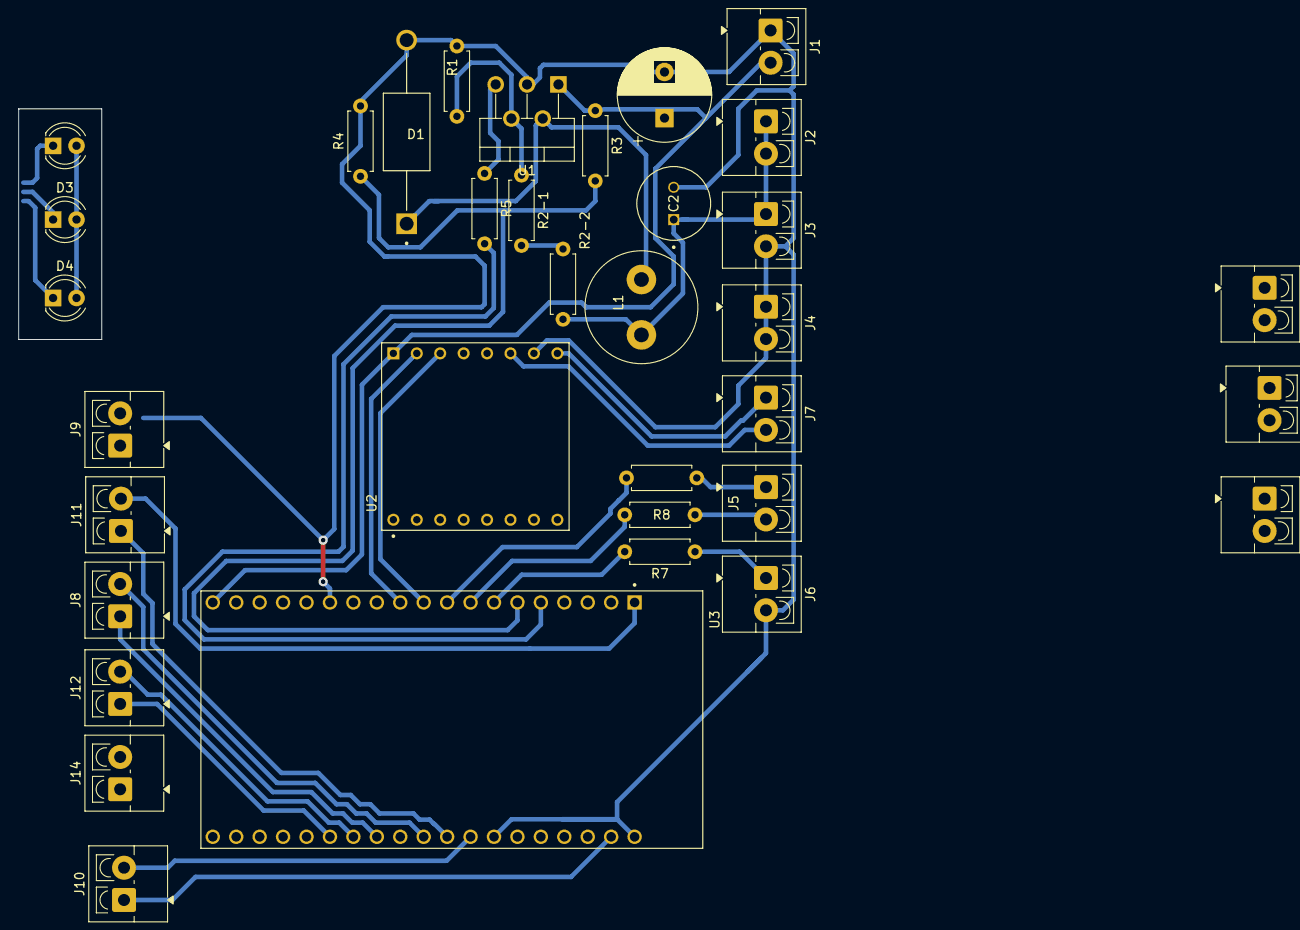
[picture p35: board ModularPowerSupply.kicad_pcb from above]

Board: 2 copper layers, 35 parts (0 on the bottom side), 36 nets.

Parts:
C2: 220u; 220uFRadialTHCAP
C3: 470 uF; CP_Radial_D10.0mm_P5.00mm
D1: D_Schottky; DIOAD1990W125L840D530
D2: RED; LED_D4.0mm
D3: YELLOW; LED_D4.0mm
D4: GREEN; LED_D4.0mm
J1: BATTERY TERMS; TerminalBlock_4Ucon_1x02_P3.50mm_Vertical
J2: 3.3V; TerminalBlock_4Ucon_1x02_P3.50mm_Vertical
J3: 3.3V AND GND; TerminalBlock_4Ucon_1x02_P3.50mm_Vertical
J4: GND; TerminalBlock_4Ucon_1x02_P3.50mm_Vertical
J5: LED'S; TerminalBlock_4Ucon_1x02_P3.50mm_Vertical
J6: LED'S AND GND; TerminalBlock_4Ucon_1x02_P3.50mm_Vertical
J7: SPEAKER; TerminalBlock_4Ucon_1x02_P3.50mm_Vertical
J8: VOLUME/JOHNS RST; TerminalBlock_4Ucon_1x02_P3.50mm_Vertical
J9: 22/GND; TerminalBlock_4Ucon_1x02_P3.50mm_Vertical
J10: 2319; TerminalBlock_4Ucon_1x02_P3.50mm_Vertical
J11: 3.3/18; TerminalBlock_4Ucon_1x02_P3.50mm_Vertical
J12: 0017; TerminalBlock_4Ucon_1x02_P3.50mm_Vertical
J13: 0504; TerminalBlock_4Ucon_1x02_P3.50mm_Vertical
J14: 0215; TerminalBlock_4Ucon_1x02_P3.50mm_Vertical
J15: 1312; TerminalBlock_4Ucon_1x02_P3.50mm_Vertical
J16: 14; TerminalBlock_4Ucon_1x02_P3.50mm_Vertical
L1: 68m; L_Radial_D12.0mm_P6.00mm_Murata_1900R
R1: 82k; R_Axial_DIN0207_L6.3mm_D2.5mm_P7.62mm_Horizontal
R2-1: 18k; R_Axial_DIN0207_L6.3mm_D2.5mm_P7.62mm_Horizontal
R2-2: 120k; R_Axial_DIN0207_L6.3mm_D2.5mm_P7.62mm_Horizontal
R3: 160k; R_Axial_DIN0207_L6.3mm_D2.5mm_P7.62mm_Horizontal
R4: 82K; R_Axial_DIN0207_L6.3mm_D2.5mm_P7.62mm_Horizontal
R5, R6, R7, R8: 330; R_Axial_DIN0207_L6.3mm_D2.5mm_P7.62mm_Horizontal
U1: LM2596T-3.3; TO-220-5_P3.4x3.7mm_StaggerOdd_Lead3.8mm_Vertical
U2: DFR0299
U3: ESP32-DEVKITC-32D; MODULE_ESP32-DEVKITC-32D

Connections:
+6V: C3.1, J1.2, R3.1, U1.1 (VIN), U2.1 (VCC), U3.J2-19 (EXT_5V)
GNDREF: C2.2, C3.2, D1.2 (A), J1.1, J3.2, J4.1, J4.2, J6.2, J9.2, R1.1, R4.2, U1.3 (GND), U2.7 (GND), U3.J2-14 (GND1), U3.J3-1 (GND3), U3.J3-7 (GND2)
unnamed: D1.1 (K), L1.2, U1.2 (OUT)
unnamed: D2.2 (A), D3.2 (A), D4.2 (A)
unnamed: C2.1, J2.1, J2.2, J3.1, L1.1, R2-2.2
unnamed: J5.1, R8.1
unnamed: J5.2, R6.1
unnamed: J6.1, R7.1
unnamed: J7.1, U2.8 (SPK2)
unnamed: J7.2, U2.6 (SPK1)
unnamed: J8.1, U3.J3-12 (IO16)
unnamed: J8.2, U3.J3-6 (IO21)
unnamed: J9.1, U3.J3-3 (IO22)
unnamed: J10.1, U3.J3-2 (IO23)
unnamed: J10.2, U3.J3-8 (IO19)
unnamed: J11.1, U3.J3-9 (IO18)
unnamed: J11.2, U3.J2-1 (3V3)
unnamed: J12.1, U3.J3-14 (IO0)
unnamed: J12.2, U3.J3-11 (IO17)
unnamed: J13.1, U3.J3-10 (IO5)
unnamed: J13.2, U3.J3-13 (IO4)
unnamed: J14.1, U3.J3-16 (IO15)
unnamed: J14.2, U3.J3-15 (IO2)
unnamed: J15.1, U3.J2-15 (IO13)
unnamed: J15.2, U3.J2-13 (IO12)
unnamed: J16.1, U3.J2-12 (IO14)
unnamed: R2-1.2, R2-2.1
unnamed: R1.2, R2-1.1, U1.4 (FB)
unnamed: R5.1, U1.5 (~ON/OFF)
unnamed: U2.2 (RX), U3.J2-11 (IO27)
unnamed: U2.3 (TX), U3.J2-10 (IO26)
unnamed: R8.2, U3.J2-9 (IO25)
unnamed: R7.2, U3.J2-7 (IO32)
unnamed: R6.2, U3.J2-8 (IO33)
unnamed: R5.2, U3.J2-5 (IO34)
unnamed: R3.2, R4.1, U3.J2-6 (IO35)

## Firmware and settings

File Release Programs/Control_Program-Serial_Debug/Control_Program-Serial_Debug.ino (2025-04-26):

/* -------------------------------------------------- */
/* NAME:    CARD-READ, FEEDBACK AV                    */
/* AUTHOR:  John Willis, Shunsuke Morosa,             */
/*            Yoseph Tefera                           */
/*                                                    */
/*                                                    */
/* PURPOSE: To read MiFare Ultralight Cards           */
/* and display the information on the ST7735          */
/* LED display from Adafruit. Playing Audio for       */
/* specific cards.                                    */
/* -------------------------------------------------- */

/* Library Includes */
#include <stdint.h>                 // Library for data types.
#include <SPI.h>                    // Arduino library for SPI controls.
#include <MFRC522.h>                // Library for RC522 scanning module.
#include "SoftwareSerial.h"         // Library for Software Communication between devices.
#include "DFRobotDFPlayerMini.h"    // Library for DFPlayer Mini module.
#include <Adafruit_GFX.h>           // Adafruit Core Graphics Library for Display module.
#include <Adafruit_ILI9341.h>       // Hardware-Specific Library for Display module.
#include <Adafruit_ImageReader.h>   // Adafruit Image Reading Functions Library for Display module.
#include <Adafruit_SPIFlash.h>      // SPI/QSPI Flash Library for reading functions.
#include <SdFat.h>                  // SD Card and FAT Functions Library for reading data and organization.

/* Definitions for Pins */
// - Scanner System
#define RC522_SS_PIN      21  // SS/SDA Pin Location for RC522
#define RC522_RST_PIN     0   // RST Pin Location for RC522
// - Audio System
#define VOLUME_UP         16  // Pin Location for Button Input - Volume Up
#define VOLUME_DOWN       32  // Pin Location for Button Input - Volume Down
#define PIN_MP3_TX        26  // Connect to Module TX Data - CONNECTS TO RX ON DFPLAYER MINI
#define PIN_MP3_RX        27  // Connect to Module RX Data - CONNECTS TO TX ON DFPLAYER MINI
// - Display System
#define TFT_DC            2   // Display DC Connection
#define TFT_CS            15  // Display Chip Select Pin Connection
#define SD_CS             5   // SD Chip Select Pin Connection
#define BCK_LIGHT         13  // Display Back Light Connection
#define BACK              22  // Pin Location for Button Input - Back
#define NEXT              14  // Pin Location for Button Input - Next
#define NAVIGATE          12  // Pin Location for Button Input - Navigate
#define BRIGHTNESS        33  // Pin Location for Button Input - Brightness
// - Charge Detection
#define ADC_PIN           35  // Pin Location for Input Voltage Detection
#define LED_PIN           25  // Pin Location for DAC Output to LED

/* Definitions for Constant Values */
// - Animal Definitions
#define ANIMAL_1          1     // Cow is on the 001.mp3 file.
#define ANIMAL_2          2     // Dog is on the 002.mp3 file.
#define ANIMAL_3          3     // Sheep is on the 003.mp3 file.
#define ANIMAL_4          4     // Horse is on the 004.mp3 file.
#define ANIMAL_5          5     // Chicken is on the 005.mp3 file.
#define ANIMAL_6          6     // Pig is on the 006.mp3 file.
#define UPDATE_SOUND      7     // Beep for updating MP3, 007.mp3 file.
// - Display Definitions
#define FREQ              5000  // PWM Frequency
#define CHANNEL           1     // PWM Channel
#define RESOLUTION        8     // PWM Channel Resolution
#define TOTALOPTIONS      2     // Total Options to Choose
// - Custom Definitions
#define TOTALANIMALS      6     // Total animals that have stickers
#define TOTALSTICKERS     4     // Total number of stickers per animal (must be highest amount no matter what, and all arrays of strings must have at least this many)

/* Card Definitions */
/* ---
NOTE:
CHANGE THE VALUES IN THE QUOTATIONS FOR YOUR NFC CARD UID (Serial Number)
YOU CAN ADD MORE QUOTATIONS WITH COMMAS IN BETWEEN AS SHOWN BELOW FOR MORE THAN ONE CARD PER ANIMAL
--- */

const char* cowCards[] = {"043CB442A51C90", "0432B442A51C90", "0438B442A51C90", "042EB442A51C90"};
const char* dogCards[] = {"0444B442A51C90", "044CB442A51C90", "0448B442A51C90", "0460B442A51C90"};
const char* sheepCards[] = {"042AB442A51C90", "0426B442A51C90", "0422B442A51C90", "041EB442A51C90"};
const char* horseCards[] = {"undefined", "0454B442A51C90", "0458B442A51C90", "0450B442A51C90"};
const char* chickenCards[] = {"041AB442A51C90", "0412B442A51C90", "0416B442A51C90", "040EB342A51C90"};
const char* pigCards[] = {"0440B442A51C90", "041AB342A51C90", "0416B342A51C90", "041EB342A51C90"};

/* Enumerators */
enum animal_ID : uint8_t    // File selection integer enumerator. This acts to display the best course of understanding to users unaffiliated with programming.
{
  COW = ANIMAL_1,
  DOG = ANIMAL_2,
  SHEEP = ANIMAL_3,
  HORSE = ANIMAL_4,
  CHICKEN = ANIMAL_5,
  PIG = ANIMAL_6,
  SOUND_UP = UPDATE_SOUND
};
enum mode : uint8_t { MENU, LEARNING, GAME };                     // Mode selection integer enumerator. This selects the current mode that algorithm is in and whether to display the menu.
enum battery_level : uint8_t { GREEN = 0, YELLOW = 1, RED = 2 };  // Charge selection to prevent flickering charge levels when averaging several different charges.

/* Class/Enumerator Creations & Associations */
// - Classes
MFRC522 rfid(RC522_SS_PIN, RC522_RST_PIN);                // Creating class for RC522 module
SoftwareSerial softwareSerial(PIN_MP3_RX, PIN_MP3_TX);    // Creating class for Serial Connection for RX/TX Pins
DFRobotDFPlayerMini player;                               // Creating class for DFPlayer Mini module
SdFat SD;                                                 // Creating class for SD Card module
Adafruit_ImageReader reader(SD);                          // Creating class for ImageReader module
Adafruit_ILI9341 tft = Adafruit_ILI9341(TFT_CS, TFT_DC);  // Creating class for Display module
// - Enumerators
animal_ID currentFile = COW;  // DEFINES THE FILES SELECTION!
mode currentMode = MENU;      // DEFINES THE GAMEMODE
battery_level charge = GREEN; // DEFINES THE CHARGE LEVEL OF THE BATTERY

/* Global Variables */
// - Button Booleans    :   Creates booleans for labeling when buttons are pressed to prevent debounce.
volatile bool upPressed = 0;            // Volume Up Button
volatile bool downPressed = 0;          // Volume Down Button
volatile bool backPressed = 0;          // Navigate Back Button
volatile bool nextPressed = 0;          // Navigate Next Button
volatile bool navigatePressed = 0;      // Navigation (Menu) Button
volatile bool brightnessPressed = 0;    // Brightness Control Button
// - Constant Characters/Integers
const char noTrigger[] = {"Volume is currently: "};                                                                 // Create a string for outputting to serial when nothing is pressed. [Interrupts Use]
const char upTrigger[] = {"Volume was Increased to: "};                                                             // Create a string for outputting to serial when up is pressed. [Interrupts Use]
const char downTrigger[] = {"Volume was Decreased to: "};                                                           // Create a string for outputting to serial when down is pressed. [Interrupts Use]
const char bothTrigger[] = {"Volume was Changed to: "};                                                             // Create a string for outputting to serial when both are pressed. [Interrupts Use]
const uint8_t brightnessLevels[] = {32, 64, 96, 128, 160, 192, 232, 255};                                           // Create an array of integers for brigthness levels.
const char* animalNames[] = {"Cow", "Dog", "Sheep", "Horse", "Chicken", "Pig"};                                     // Create an array of strings for animal names for printing.
const char* imageFiles[] = {"3cow3.bmp", "3dog2.bmp", "3sheep1.bmp", "3horse1.bmp", "3chicken4.bmp", "3pig3.bmp"};  // Create an array of strings for file names for images pertaining to animals.
const float SCALE_FACTOR = 2.95*5.08/4.7;                                                                           // Adjustment value for voltage divider.
// - Starting Values & Globals
volatile bool isPlaying = 0;            // Create a boolean for whether the audio player is playing audio.
volatile bool scanBacked = 0;           // Create a boolean for whether the scan has been backed or not.
volatile uint8_t volume = 21;           // Volume Control Integer. Initial Volume is 15, volume ranges from 0-30.
volatile uint8_t brightness = 128;      // Brightness Control Integer. Initial brightness is 128, brightness ranges from 32-255.
volatile uint8_t levelIndex = 3;        // Brightness Array Indexer.
volatile uint8_t selectedOption = 0;    // Option selector integer.
char uid[32];                           // Create a 32 byte array for UID (well over what it needs).
volatile uint16_t adcValue = 0;         // Create a 16-bit value to hold the ADC value (0-4095). (Volatile for safety.)
volatile float voltage = 0;             // Create a float value that will change for voltage. (Volatile for safety.)

/* Interrupt Service Routines for button presses. */
/// <summary>
///   Increases the volume of the DFPlayer Mini for the Speakers.
///   **  Does not change if volume up button was previously pressed.
/// </summary>
void IRAM_ATTR ISR_volumeUp()
{
  if (volume < 30 && !upPressed)
  {
    volume = volume + 3;                // Maximum volume is 30, check underneath.
    volume = volume > 30 ? 30 : volume; // Ensures volume is within the dedicated range. Redundancy.
    upPressed = true;
  }
}

/// <summary>
///   Decreases the volume of the DFPlayer Mini for the Speakers.
///   **  Does not change if volume down button was previously pressed.
/// </summary>
void IRAM_ATTR ISR_volumeDown()
{
  if (volume > 0 && !downPressed)
  {
    volume = volume - 3;              // Ninimum volume is 0, check underneath.
    volume = volume < 0 ? 0 : volume; // Ensures volume is within the dedicated range. Redundancy.
    downPressed = true;
  }
}

/// <summary>
///   These two functions, ISR_BACK and ISR_NEXT, are simple checkstatements.
///   **  These do not execute if button was previously pressed.
///   **  These are condensed.
/// </summary>
void IRAM_ATTR ISR_BACK() { if (!backPressed) backPressed = true; }
void IRAM_ATTR ISR_NEXT() { if (!nextPressed) nextPressed = true; }

/// <summary>
///   Changes the selected option for the menu screen.
///   **  Does not change if the navigate button was previously pressed.
/// </summary>
void IRAM_ATTR ISR_NAVIGATE() 
{
  if (!navigatePressed)
  {
    selectedOption = (selectedOption + 1) % TOTALOPTIONS;
    navigatePressed = true;
  }
}

/// <summary>
///   Changes the brightness of the backlight on the LED Display.
///   **  Does not change if the brightness button was previously pressed.
/// </summary>
void IRAM_ATTR ISR_BRIGHTNESS()
{
  if (!brightnessPressed)
  {
    levelIndex = (levelIndex + 1) % RESOLUTION;
    brightness = brightnessLevels[levelIndex];
    brightnessPressed = true;
  }
}

void setup()
{
  /* Initializations */
  Serial.begin(9600);           // Initialize the serial communication with the computer.
  SPI.begin();                  // Initialization for the SPI bus for slave devices.
  rfid.PCD_Init();              // Initialization for the RC522 module.
  softwareSerial.begin(9600);   // Initialization for the DFPlayer Mini module.
  tft.begin();                  // Initialization for display module.
  tft.setRotation(1);           // Set display module to landscape mode.

  /* Line Clears */
  Serial.println();                                       // Clear the line for beginning of serial output.
  Serial.println();                                       // Add an additional cleared line for cleanliness.
  Serial.println(F("<RC522 Successfully Setup>"));        // Display initialization success for RC522 to serial window.

  /* Assign Button Inputs */
  // - Button Inputs
  pinMode(VOLUME_UP, INPUT_PULLUP);     // "Volume Up" button
  pinMode(VOLUME_DOWN, INPUT_PULLUP);   // "Volume Down" button
  pinMode(BACK, INPUT_PULLUP);          // "Back" button
  pinMode(NEXT, INPUT_PULLUP);          // "Next" button
  pinMode(NAVIGATE, INPUT_PULLUP);      // "Navigate" button
  pinMode(BRIGHTNESS, INPUT_PULLUP);    // "Brightness" button
  // - Button Interrupts
  attachInterrupt(VOLUME_UP, ISR_volumeUp, FALLING);      // Attach interrupt to Volume Up button.
  attachInterrupt(VOLUME_DOWN, ISR_volumeDown, FALLING);  // Attach interrupt to Volume Down button.
  attachInterrupt(BACK, ISR_BACK, FALLING);               // Attach interrupt to Back button.
  attachInterrupt(NEXT, ISR_NEXT, FALLING);               // Attach interrupt to Next button.
  attachInterrupt(NAVIGATE, ISR_NAVIGATE, FALLING);       // Attach interrupt to Navigate button.
  attachInterrupt(BRIGHTNESS, ISR_BRIGHTNESS, FALLING);   // Attach interrupt to Brightness button.
  // - Confirmation
  Serial.println(F("<Buttons Configured>"));              // Print that the button is configured.

  /* Start Communication with DFPlayer Mini */
  if (player.begin(softwareSerial))
  {
    Serial.println("<DFPlayer Mini Successfully Setup>");

    // Set initial volume
    player.volume(volume);
  }
  else
    Serial.println("<DFPlayer Mini Failed Setup>");

  /* Start Communication with SD Card */
  if (!SD.begin(SD_CS, SD_SCK_MHZ(10))) // Initialization for SD Card.
  {
    Serial.println(F("<SD Initialization Failed!>"));
    for (;;);
  }
  else
    Serial.println(F("<SD Card Successfully Setup>"));      // Display initialization success for SD Card to serial window.

  /* Start Display Setup */
  ledcAttachChannel(BCK_LIGHT, FREQ, RESOLUTION, CHANNEL);  // Setup backlight.
  ledcWrite(BCK_LIGHT, brightness);                         // Set initial brightness to 50%.
  Serial.println(F("<LED Screen Successfully Setup>"));     // Initialization for display.

  /* Confirmations for data, display in terminal. */
  Serial.println(F("<Program Successfully Setup>"));                                  // State success of program setting up.
  Serial.println(F("This program is intended to scan Mifare Ultralight Cards."));     // Specify acceptable card types in serial window.
  Serial.println(F("Scan card to see data as follows: UID and PICC Type."));          // Give directions in Serial Window for what to scan.
  Serial.println();                                                                   // Add another clear line for cleanliness.

  for (uint8_t i = 0; i < 10; i++)  // Set default values to 0.
    uid[i] = 0;
  
  /* Initialize Program */
  randomSeed(analogRead(34)); // set it to un used pin
  drawMenu();
}

void loop()
{
  if (backPressed) { backPressed = false; drawMenu(); }
  if (nextPressed) { nextPressed = false; selectOption(); }
  if (navigatePressed) { navigatePressed = false; moveSelector(); }
  if (brightnessPressed) { brightnessPressed = false; brightnessControl(); }

  checkVolume();
  checkAudio();
  checkCharge();

  delay(1000);
}

/* ------------------------------------------------------------ */
/* Functions for Display Control and Algorithm/Gamemode Control */
/* ------------------------------------------------------------ */

/// <summary>
///   Draws the entire screen, filling with appropriate text for options.
///   **  This is a display function, and interacts with only the display.
/// </summary>
void drawMenu()
{
  currentMode = MENU;
  tft.fillScreen(ILI9341_BLACK);
  tft.setCursor(50, 0);
  tft.setTextColor(ILI9341_WHITE);
  tft.setTextSize(4);
  tft.println("Main Menu");
  // Draw Option 1
  tft.setCursor(20, 50);
  tft.setTextColor(selectedOption == 0 ? ILI9341_YELLOW : ILI9341_WHITE);
  tft.setTextSize(3);
  tft.println("> Learning Mode");
  // Draw Option 2
  tft.setCursor(20, 90);
  tft.setTextColor(selectedOption == 1 ? ILI9341_YELLOW : ILI9341_WHITE);
  tft.setTextSize(3);
  tft.println("> Game Mode");
  // Instructions at the bottom
  tft.setTextSize(2);
  tft.setTextColor(ILI9341_WHITE);
  tft.setCursor(10, 140);
  tft.println("Press Navigate to move");
  tft.setCursor(10, 180);
  tft.println("Press Next to select");
  tft.setCursor(10, 220);
  tft.println("Press Back to return");
}

/// <summary>
///   Update Functions for Display and Menu.
///   Controls Brightness and Calls other Update Functions.
///   **  These functions update display.
/// </summary>
void moveSelector() { drawMenu(); }
void brightnessControl() { ledcWrite(BCK_LIGHT, brightness); }

/// <summary>
///   Updates the current mode option and calls the function
///   based on the selected option.
///   **  This function sets the algorithm selection.
/// </summary>
void selectOption()
{
  tft.fillScreen(ILI9341_BLACK);
  
  if (selectedOption == 0)
  {
    currentMode = LEARNING;
    nextPressed = 0;
    learningMode();
  } 
  else
  {
    currentMode = GAME;
    nextPressed = 0;
    gameMode();
  }
}

/// <summary>
///   This function runs the Learning Mode for active feedback on pieces.
///   ** This is an algorithm implemented in a separate loop from main.
/// </summary>
void learningMode()
{
  currentMode = LEARNING;
  backPressed = false;  

  while (!backPressed)
  {
    if (backPressed) { backPressed = false; drawMenu(); return;}
    if (brightnessPressed) { brightnessPressed = false; brightnessControl(); }

    checkVolume();
    checkAudio();
    checkCharge();
      
    tft.fillScreen(ILI9341_BLACK);
    tft.setCursor(100, 0);
    tft.setTextSize(2);
    tft.setTextColor(ILI9341_WHITE);
    tft.println("Learning Mode");
    tft.setCursor(100, 20);
    tft.println("Place animal");

    checkCardScan();
    if (scanBacked)
    {
      scanBacked = false;
      currentMode = MENU;
      drawMenu();
      return;
    }

    tft.setCursor(140, 40);
    tft.setTextSize(2);
    tft.setTextColor(ILI9341_WHITE);
    tft.println(animalNames[currentFile - 1]);
    reader.drawBMP(imageFiles[currentFile - 1], tft, 10, 60);
    
    playAudio();
    
    Serial.println(animalNames[currentFile - 1]);

    delay(3000);
  }
  drawMenu();
}

/// <summary>
///   This runs the Game Mode for testing pieces and playing audio/pictures prior to scan.
///   **  This is an algorithm implemented separate from the main loop.
/// </summary>
void gameMode()
{
  uint8_t score = 0;
  uint8_t availableAnimals[TOTALANIMALS] = {ANIMAL_1, ANIMAL_2, ANIMAL_3, ANIMAL_4, ANIMAL_5, ANIMAL_6};  // MUST BE THE SAME AMOUNT OF ANIMALS AS TOTALANIMALS
  uint8_t remaining = TOTALANIMALS;  // IS LINKED TO SAME SYSTEM AS availableAnimals

  backPressed = false;  // Reset back button flag before game starts

  while (remaining > 0)
  {
    uint8_t randIndex = random(remaining);
    uint8_t targetAnimal = availableAnimals[randIndex];  // Select a random animal

    tft.fillScreen(ILI9341_BLACK);
    tft.setCursor(100, 0);
    tft.setTextSize(2);
    tft.setTextColor(ILI9341_WHITE);
    tft.println("Game Mode");

    switch(targetAnimal)
    {
      case 1: currentFile = COW; break;
      case 2: currentFile = DOG; break;
      case 3: currentFile = SHEEP; break;
      case 4: currentFile = HORSE; break;
      case 5: currentFile = CHICKEN; break;
      case 6: currentFile = PIG; break;
      default: currentFile = COW; break;
    }
    playAudio();
    checkCharge();
    
    delay(1000);

    tft.setCursor(20, 20);
    tft.println("Place the correct animal");

    while (true)
    {
      if (backPressed) { backPressed = false; drawMenu(); return;}
      if (brightnessPressed) { brightnessPressed = false; brightnessControl(); }

      checkVolume();
      checkAudio();
      checkCharge();
      checkCardScan();

      if (scanBacked)
      {
        scanBacked = false;
        currentMode = MENU;
        drawMenu();
        return;
      }

      if (currentFile == targetAnimal)
      {
        // **Correct answer: update score and remove used animal**
        score++;
        availableAnimals[randIndex] = availableAnimals[remaining - 1];  // Replace with last element
        remaining--;  // Reduce available options

        //tft.fillScreen(ILI9341_BLACK);
        tft.setCursor(50, 40);
        tft.setTextSize(2);
        tft.setTextColor(ILI9341_GREEN);
        tft.println("Correct!");
        tft.setCursor(170, 40);
        tft.println(animalNames[currentFile - 1]);
        reader.drawBMP(imageFiles[currentFile - 1], tft, 10, 60);
        // play sound here
        delay(1000);
        break;  // Move to next round
      }
      else
      {
        // **Incorrect answer: Show "Try Again" message**
        //tft.fillScreen(ILI9341_BLACK);
        tft.setCursor(100, 40);
        tft.setTextSize(2);
        tft.setTextColor(ILI9341_RED);
        tft.println("Try Again");
        delay(1000);
        
        // **Re-display the prompt**
        tft.fillScreen(ILI9341_BLACK);
        tft.setCursor(100, 0);
        tft.setTextSize(2);
        tft.setTextColor(ILI9341_WHITE);
        tft.println("Game Mode");
        tft.setCursor(20, 20);
        tft.println("Place the correct animal");
      }

      delay(700);  // Prevent rapid detection spam
    }
  }

  // **Game Over: Display final score and return to menu**
  tft.fillScreen(ILI9341_BLACK);
  tft.setCursor(100, 0);
  tft.setTextSize(2);
  tft.setTextColor(ILI9341_WHITE);
  tft.println("Game Over");
  tft.setCursor(100, 110);
  tft.print("Score: ");
  tft.println(score);
  delay(3000);
  currentMode = MENU;
  drawMenu();
  return;
}

/* ---------------------------------------------------- */
/* Functions for playing Audio and setting Enumerators. */
/* ---------------------------------------------------- */
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

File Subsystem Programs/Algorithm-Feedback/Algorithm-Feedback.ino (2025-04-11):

#include "SPI.h"
#include <Adafruit_GFX.h>         // Core graphics library
#include <Adafruit_ILI9341.h>     // Hardware-specific library
#include <SdFat.h>                // SD card & FAT filesystem library
#include <Adafruit_SPIFlash.h>    // SPI / QSPI flash library
#include <Adafruit_ImageReader.h> // Image-reading functions

const int freq = 5000; // PWM frequency        
const int channel = 1;  // PWM channel      
const int resolution = 8;  // PWM channel    
int brightnessLevels[] = {32, 64, 96, 128, 160, 192, 232, 255};  
int brightness = 128;  // Initial brightness (50%)        
int levelIndex = 0;  // Index to track brightness level   

const char* animalNames[] = {"Pig", "Chicken", "Dog", "Horse", "Cow", "Sheep"};
const char* imageFiles[] = {"3pig3.bmp", "3chicken4.bmp", "3dog2.bmp", "3horse1.bmp", "3cow3.bmp", "3sheep1.bmp"};

// Global interrupt flags for buttons
volatile bool backPressed = false;
volatile bool nextPressed = false;
volatile bool navigatePressed = false;
volatile bool brightnessPressed = false;

// TFT display and SD card
//#define TFT_DC 2  
//#define TFT_CS 15  
#define SD_CS 5  

#define TFT_DC 2
#define TFT_CS 15
#define TFT_MOSI 23
#define TFT_CLK 18
#define TFT_RST 4
#define TFT_MISO 19

// PWM Backlight Control
#define BCK_LIGHT 13  

// Button Pins
#define BTN_PIN1 22  // Back
#define BTN_PIN2 14  // Next
#define BTN_PIN3 12  // Navigate
#define BTN_PIN4 33  // Brightness control

// Button States (for edge detection)
bool lastButtonState1 = HIGH;
bool lastButtonState2 = HIGH;
bool lastButtonState3 = HIGH;
bool lastButtonState4 = HIGH;

SdFat SD;
Adafruit_ImageReader reader(SD);
//Adafruit_ILI9341 tft = Adafruit_ILI9341(TFT_CS, TFT_DC);
Adafruit_ILI9341 tft = Adafruit_ILI9341(TFT_CS, TFT_DC, TFT_RST);
//Adafruit_ILI9341 tft = Adafruit_ILI9341(TFT_CS, TFT_DC, TFT_MOSI, TFT_CLK, TFT_RST, TFT_MISO);

int selectedOption = 0;
const int totalOptions = 2;
enum Mode { MENU, LEARNING, GAME };
Mode currentMode = MENU;

// Interrupt Service Routines for buttons
void IRAM_ATTR backISR() { backPressed = true; }
void IRAM_ATTR nextISR() { nextPressed = true; }
void IRAM_ATTR navigateISR() { navigatePressed = true; }
void IRAM_ATTR brightnessISR() { brightnessPressed = true; }

void setup() {
  Serial.begin(115200);

  SPI.begin(TFT_CLK, TFT_MISO, TFT_MOSI, SD_CS);

  pinMode(SD_CS, OUTPUT);
  digitalWrite(SD_CS, HIGH);
  // pinMode(TFT_CLK, OUTPUT);
  // pinMode(TFT_MOSI, OUTPUT);
  // pinMode(TFT_MISO, OUTPUT);

  tft.begin();
  tft.setRotation(1); //Landscape mode

  // tft.fillScreen(ILI9341_BLUE);
  // delay(3000);
  
  if (!SD.begin(SD_CS, SD_SCK_MHZ(10))) {
      Serial.println(F("SD initialization failed!"));
      for (;;);
  }

  // Set up buttons as input with pull-up and attach interrupts
  pinMode(BTN_PIN1, INPUT_PULLUP);
  pinMode(BTN_PIN2, INPUT_PULLUP);
  pinMode(BTN_PIN3, INPUT_PULLUP);
  pinMode(BTN_PIN4, INPUT_PULLUP);

  
  
  attachInterrupt(BTN_PIN1, backISR, FALLING);
  attachInterrupt(BTN_PIN2, nextISR, FALLING);
  attachInterrupt(BTN_PIN3, navigateISR, FALLING);
  attachInterrupt(BTN_PIN4, brightnessISR, FALLING);

  ledcAttachChannel(BCK_LIGHT, freq, resolution, channel);
  ledcWrite(BCK_LIGHT, brightness); // set initial brightness to half 50%

  randomSeed(analogRead(34)); // set it to un used pin
  drawMenu();
}

void loop() {
  if (currentMode == MENU || currentMode == GAME) {
      if (backPressed) {
          backPressed = false;
          drawMenu();
      }
      if (nextPressed) {
          nextPressed = false;
          selectOption();
      }
      if (navigatePressed) {
          navigatePressed = false;
          moveSelector();
      }
      if (brightnessPressed) {
          brightnessPressed = false;
          brightnessControl();
      }
  }
  if (currentMode == LEARNING) {
      learningMode();
  }
}


void drawMenu() {
  currentMode = MENU;
  tft.fillScreen(ILI9341_BLACK);
  tft.setCursor(50, 0);
  tft.setTextColor(ILI9341_WHITE);
  tft.setTextSize(4);
  tft.println("Main Menu");
  // Draw Option 1
  tft.setCursor(20, 50);
  tft.setTextColor(selectedOption == 0 ? ILI9341_YELLOW : ILI9341_WHITE);
  tft.setTextSize(3);
  tft.println("> Learning Mode");
  // Draw Option 2
  tft.setCursor(20, 90);
  tft.setTextColor(selectedOption == 1 ? ILI9341_YELLOW : ILI9341_WHITE);
  tft.setTextSize(3);
  tft.println("> Game Mode");
  // Instructions at the bottom
  tft.setTextSize(2);
  tft.setTextColor(ILI9341_WHITE);
  tft.setCursor(10, 140);
  tft.println("Press Navigate to move");
  tft.setCursor(10, 180);
  tft.println("Press Next to select");
  tft.setCursor(10, 220);
  tft.println("Press Back to return");
}

void moveSelector() {
  selectedOption = (selectedOption + 1) % totalOptions;
  drawMenu();
}

void brightnessControl() {
  levelIndex = (levelIndex + 1) % 8; // Cycle through brightness levels
  brightness = brightnessLevels[levelIndex]; // Update PWM value
  ledcWrite(BCK_LIGHT, brightness);
}

void selectOption() {
  tft.fillScreen(ILI9341_BLACK);
  if (selectedOption == 0) {
      currentMode = LEARNING;
      learningMode();
  } else {
      currentMode = GAME;
      gameMode();
  }
}

// Learning mode
void learningMode() {
  currentMode = LEARNING;
  backPressed = false;  

  while (!backPressed) {
      if (brightnessPressed) {
          brightnessControl();
          brightnessPressed = false;
      }
      
      tft.fillScreen(ILI9341_BLACK);
      tft.setCursor(0, 0);
      tft.setTextSize(2);
      tft.setTextColor(ILI9341_WHITE);
      tft.println("Learning Mode");
      tft.setCursor(0, 20);
      tft.println("Place animal");

      int detectedAnimal = random(6); // sensor data input here

      const char* animalNames[] = {"Pig", "Chicken", "Dog", "Horse", "Cow", "Sheep"};
      const char* imageFiles[] = {"3pig3.bmp", "3chicken4.bmp", "3dog2.bmp", "3horse1.bmp", "3cow3.bmp", "3sheep1.bmp"};

      tft.setCursor(50, 40);
      tft.setTextSize(2);
      tft.setTextColor(ILI9341_WHITE);
      tft.println(animalNames[detectedAnimal]);
      reader.drawBMP(imageFiles[detectedAnimal], tft, 10, 60);
      // play sound here
      Serial.println(animalNames[detectedAnimal]);

      delay(3000);
  }
  drawMenu();
}
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

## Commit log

2025-01-16 Port Previous Repository (#2)
    This ports all previous repository effects.
    [Arduino-Uno-r3-with-RFID-RC522.fzz]
2025-01-16 Update Speaker Toy Test Files (#4)
    * Minor change, correcting defintions.
    * Move files.
    [AnimalCrateTOY.ino]
2025-01-21 Delete the AnimalCrateTOY File (#11)
    This file no longer is used in this repository and does not work with the hardware for the individual toys. We're removing this for now to prevent any conflicts in the future.
    [AnimalCrateTOY.ino]
2025-01-21 Move to a dedicated folder for Arduino Formatting. (#13)
2025-01-22 Create AnimalToy1.0.ino (#14)
    This is the first edition of the code before I added the sound files in that will upload directly to the Arduino for the Animal sounds. Currently this code only produces a beep when the device is sha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
2025-01-22 Add Arduino Files to Labeler (#15)
    This adds the .ino extension to the labeler so it doesn't forget to flag Arduino changes.
2025-02-19 Create AnimalToy2.0 (#16)
    This version of the code shows the changes made to initialize the DF Player Mini with the sound file that is on there for the animal after the device is shaken. As well as the circuit now includes a 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
2025-02-20 Fix AnimalToy code. (#18)
    This fixes the structure and turns it into a .ino file so that it follows the required naming scheme that Arduino uses.
2025-03-11 Create SoundWithbuttons.ino (#19)
    Plays sound with a push button and changes volume also.
2025-03-27 Update Labeler for PCB Files (#31)
    Updates the labeler auto-check for the PCB Files.
2025-03-27 Adding Kicad PCB and Schematic Files (#29)
    * Adding Kicad PCB and Schematic Files
    * Sort in Directory 1
    * Sort in Directory 2
    * Sort in Directory 3
    * Change 1 Again
    * Change 2 Again
    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
    [490 Power Supply Circuit.kicad_pcb, 490 Power Supply Circuit.kicad_sch]
2025-04-03 Interrupts Setup & Remove Display in Audio/Scanner Integration (#33)
    * Initial commit, removing display and setting up hardware interrupts. This has problems, do not make a PR without checking this over.
    * Sets up the rest of the interrupts with a play by button sound system.
    [ScannerAudioIntegration.ino]
2025-04-05 Upload new KiCad Files. (#37)
    [490 Power Supply Circuit.kicad_pcb, 490 Power Supply Circuit.kicad_sch]
2025-04-05 Update KiCad Organization and README (#38)
    * Update Organization and Provide README for KiCad Building Resources.
    * Provide README
    [490 Power Supply Circuit.kicad_pcb, 490 Power Supply Circuit.kicad_sch, ModularPowerSupply.kicad_pcb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]
2025-04-08 Audio/Video & Scanner Integration (#41)
    * Initial Branch
    * Additional Additions.
    * Fix one noticed mistake. Change to volatile due to ISR.
    * Finish Integration. Tests Remain.
    * Fix ISR.
    [AV_ScannerIntegration.ino]
2025-04-08 Integration Program TouchUps (#40)
    * Fix PURPOSE section.
    * More Touchups
    * More touchups.
    [ScannerAudioIntegration.ino]
2025-04-10 Massive update fix for current play board. Fixes screen issues as well. (#43)
    [AV_ScannerIntegration.ino]
2025-04-11 Fix BCK_LIGHT Pin and Setup (#44)
    Fixes setup for Arduino IDE.
2025-04-12 Update Prerequisites and MFRC Directory (#48)
    [Arduino-Uno-r3-with-RFID-RC522.fzz]
2025-04-12 Fix Bad Directory (#49)
    [Arduino-Uno-r3-with-RFID-RC522.fzz]
2025-04-12 Update PCB Auto-Labeler (#50)
    * Update PCB Auto-Labeler
    * Update labeler.yml
2025-04-12 Update the KiCad Files for Split Design (#51)
    [DFPlayer and LCD.kicad_pcb, DFPlayer and LCD.kicad_sch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]
2025-04-14 Fix gameMode() in AV_ScannerIntegration (#53)
    [AV_ScannerIntegration.ino]
2025-04-17 Fix GameMode() Indexing Errors in Integration & Release (#55)
    [AV_ScannerIntegration.ino, Control_Program-Serial_Debug.ino]
2025-04-26 Update KiCad Files (#59)
    [DFPlayer and LCD.kicad_pcb, DFPlayer and LCD.kicad_sch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]
2025-04-26 Fix Indexing, Screen Repeats, Spacing on Menu, and Add Volume Cue (#60)
    [AV_ScannerIntegration.ino, Control_Program-Serial_Debug.ino, Control_Program.ino]
2025-04-26 Add Charge_Detection Subsystem (#61)
2025-04-26 Add Charge Detection to Releases (#62)
2025-05-05 Add CAD to Labeler (#63)
2025-05-05 Finish Building Resources - Adding CAD Designs (#64)
    [Barn Body Back.STL, Barn Body Front.STL, EEBarn5shelf1.STL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]
